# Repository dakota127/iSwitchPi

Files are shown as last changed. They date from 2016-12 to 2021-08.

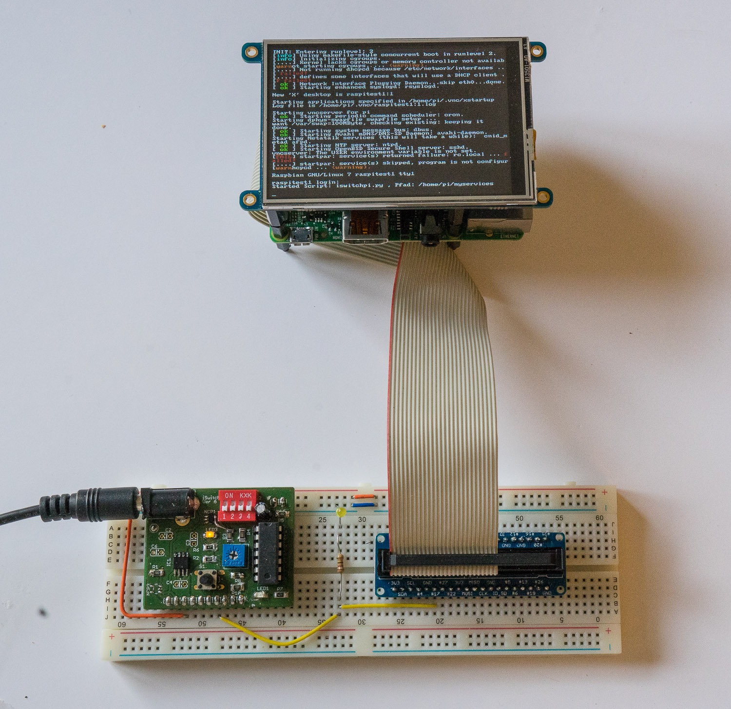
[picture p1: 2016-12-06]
Docu/supporting docu/iswitchpi_testwithpi.jpg

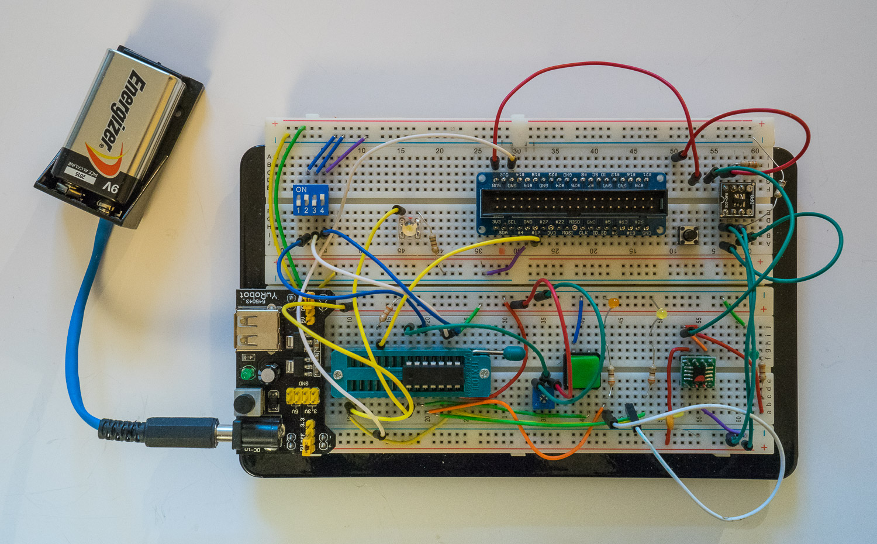
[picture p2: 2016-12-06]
Docu/supporting docu/iswitchpi_testsetup.jpg

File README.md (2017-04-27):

# iSwitchPi
Intelligent Power Switch for Raspberry Pi 

Native Raspberry Pi does not have an On/Off switch and there is no easy way
to shutdown the Pi while keeping the filesystem intact.
This Intelligent Power Switch allows just that: 
Power-On the Pi by pressing a pushbutton and also properly Power-Off
the Pi with another press on the same button.
The intelligence is provided by a program running in an AVR MCU ATtiny44.
This C-program implements a Finite State Machine in the MCU.
A small Python script is running in the Pi itself. 
Just one GPIO-Pin is used for two-way communication.
In addition, a variable frequency square wave is available for externally interrupting the Pi.

Formfactor: Raspi hat with 2x20 Pins for other hats on top of iSwitchPi.

Full Documentation, Code and EagleCAD files on GitHub. 
Documentation is in English and German.
Quick Start guide explains installation.  
See state diagram to understand operation of iSwitchPi

Also check out my project webpage at 
http://projects.descan.com/projekt5.html

Update April 2017:
In April of 2017 an update was made to the firmware in the ATtiny44. 
A user requested an auto-power-on functionality: the Pi should restart 
unattended (meaning without the need to press the ON-pushbutton) when 5 Volt comes back after a power failure. 
State 0 was added to the state diagram  and position 4 of dip-switch 3 is used to select/deselect this feature.

Free to use, modify, and distribute with proper attribution.
Frei für jedermann, vollständige Quellangabe vorausgesetzt.

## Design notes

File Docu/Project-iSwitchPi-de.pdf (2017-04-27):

# Projektbeschreibung iSwitchPi

# Intelligenter Power Switch für Raspberry Pi

Beschreibung eines intelligenten Ein/Aus-Schalters für den Raspberry Pi

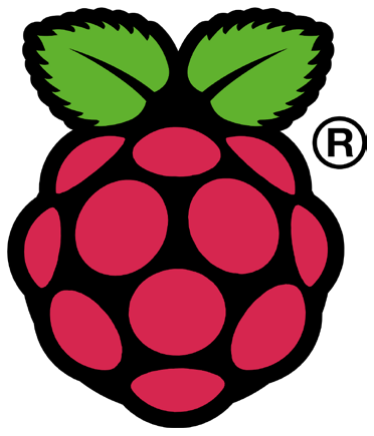
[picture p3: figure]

### Intelligent Power Switch Seite 3

Inhaltsverzeichnis

## 1. Was ist ein Raspberry Pi

Der Raspberry Pi (genannt Pi) ist ein kreditkarten-kleiner und preisgünstiger (45 CHF) Linux Computer der sich seit seiner Einführung vor bald 4 Jahren grosser Beliebtheit erfreut und der bereits mehrere Millionen Mal verkauft wurde. Im Internet finden sich unzählige Projektbeschreibungen; alles Mögliche und Unmögliche wird mit diesem Micro-Computer gebaut. Der Initiant Eben Upton ist Engländer und in folgendem Video auf YouTube erklärt die Geschichte des Pi.
Eben Upton on YouTube (https://www.youtube.com/watch?v=6xFzVuxldqs)
Der Pi hat 4 USB-Anschlüsse, einen Lan-Anschluss, ein HDMI-Anschluss für Monitor und einen Audio-Video-Ausgang. Ebenfalls auf dem Board ist ein Anschluss für die Pi-Camera - eine HD-fähige Kleinst-Camera für Fotos und Video. Was den Pi auszeichnet, ist die 40-polige Steckerleiste. Viele dieser Anschlüsse sind General Purpose Input/Output Pins, welche in Progammen angesteuert/gelesen werden können. Es gibt in der Zwischenzeit vielfältige Expansion Boards von unzähligen Anbietern. Der Pi konsumiert bloss 1 Watt Leistung: 5V und 100mA Strom.
Dieses Maschinchen hat mich von Anfang an fasziniert, ich hatte mir in 2012 eines angeschafft. Nach einigem Probieren legte ich es auf die Seite - fand einfach kein wirkliches Projekt. Dies hat sich im Frühjahr 2014 geändert und es kam die Idee auf für ein erstes Pi-Projekt: Lampensteuerung bei Ferienabwesenheit. In der Zwischenzeit (Stand Anfangs 2016) sind bereits drei weitere Raspi-Projekte dazugekommen: Light-Painting Pixeslstab mit 144 Led und ein, wie ich es nenne, Christmax TV. Raspi und Volumio als Musikplayer in einer weihnachtlichen Box. Details zu diesen Projekten findet man auf der Projekt-Website. (http://projects.descan.com)

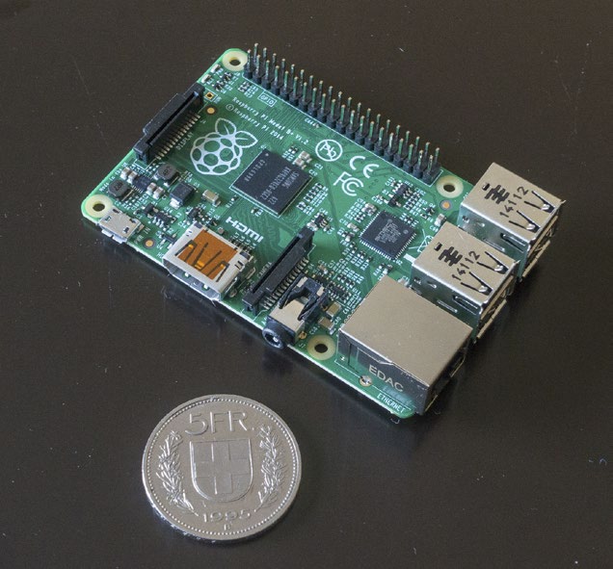
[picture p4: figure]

Der Raspberry PI Model B+

## 2. Abstract

A Raspberry Pi does not have an On/Off switch and there is no easy way to shutdown the Pi while keeping the filesystem intact.
This Intelligent Power Switch brings a clever solution to this problem: Power-On the Pi by pressing a pushbutton and also properly Power-Off the Pi with another press on the same button.
The intelligence is provided by a program running in an AVR MCU ATtiny44. This C-program implements a Finite State Machine in the MCU.
A small Python script is running in the Pi itself.
Just one GPIO-Pin is used for two-way communication between the Pi and the iSwitchPi board.
The iSwitchPi board additionally provides a square wave output with variable frequeny that can be used to trigger interrupts on the Pi.

## 3. Anforderungen

Während der Entwicklung verschiedener Gadgets mit dem Raspberry Pi tauchten immer wieder verschiedene Themen und Problemstellungen auf, für die ich gerne eine elegante Lösung gehabt hätte. So entstand der Plan, ein Add-on zu entwickeln. Folgende Anforderungen wurden definiert:
- Eine elegante Lösung für das Ein- und Ausschalten des Pi‘s zu haben.
- Das Bauteil soll in der Form eines Pi-Hats erstellt werden.
- Es soll bloss ein einziger GPIO-Pin des Pi für die Kommunikation verwendet werden.
- Das Bauteil soll wahrnehmen können, wenn der Pi nicht mehr läuft. Es soll in diesem Fall die Power -Down Sequenz gestartet werden.
- Das Bauteil soll überdies ein Rechteck-Signal von 0.5 Hz bis ca. 100 Hz erzeugen - viele Pi-Anwendungen benötigen eine externe Rechteck-Quelle, mit welcher Timer-Interrupts realisiert werden können. Ein Mikrocontroller erledigt diese Aufgabe ohne viel Programmier-Aufwand.

Wichtigste Anforderung: Bekanntermassen ist das Ausschalten eines Raspberry Pi (Power Off) - genauso wie das Ausschalten jedes anderen Computers - in zwei Schritten zu bewerkstelligen:
- a: der Pi muss ordentlich mit einem Shutdown oder halt Command heruntergefahren werden - dies kann nur in einem Stück Software auf dem Pi erledigt werden.
- b: erst danach kann extern die Stromzufuhr gekappt werden.

Das Einschalten ist dagegen simpel: Stromzufuhr einschalten und der Pi bootet und beginnt mit der vorgesehenen Arbeit.
Es gibt auf dem Markt verschiedene Add-ons zu kaufen, welches das Ein-Ausschalt-Problem lösen. Sie bestehen meist aus einer kleinen gedruckten Schaltung mit Anschlüssen für Drucktasten, 5 V und anderen nötigen Verbindungen. Diese kleinen Bauteile funktionieren gut, und es ist nicht nötig, die genaue interne Funktionsweise zu verstehen.
Dieses Projekt soll die genannten Anforderungen in Hardware und Software realisieren.

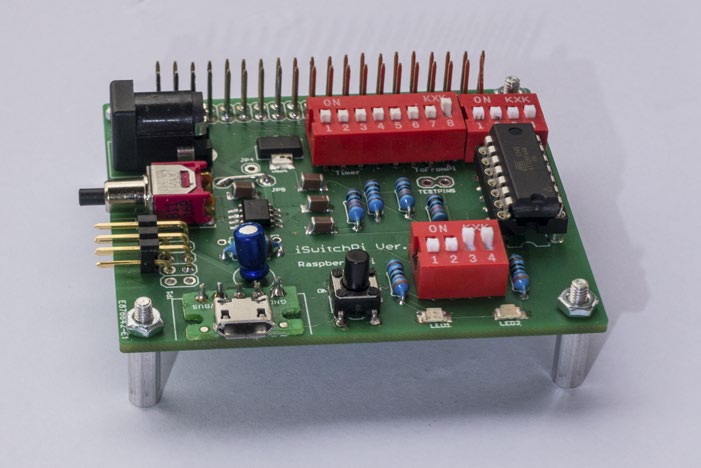
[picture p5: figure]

Die fertige iSwitchPi Platine

## 4. Vorgehen

## 4.1 Umschau auf dem Markt

Zuerst wurden einige auf dem Markt angebotenen Add-ons genauer studiert. Folgende Produkte und/oder Anleitungen wurden unter die Lupe genommen:
- Pi-Supply der Englischen Firma Pi-Supply. (https://www.pi-supply.com/) Dieses Add-on war schon bei mir im Einsatz, es funktioniert sehr gut, ungünstig ist jedoch, dass für Einschalten und Ausschalten zwei verschiedene Drucktasten verwendet werden. Die eingesetzte elektronische Schaltung ist an anderer Stelle im Internet zu finden. Kommt wegen der Lösung mit zwei Tasten nicht in Frage. Benötigt 2 GPIO Pins beim Pi.
- Pi-Shutdown Button bei Instructables: (http://www.instructables.com/id/Raspberry-Pi-Shutdown-Button/) Lösung mit embedded Controller ATtiny13/85. Dies kommt der Vorstellung schon sehr nahe.
- ATX-Raspi von LowPowerLab. (https://lowpowerlab.com/shop/ATXRaspi-R2) Dieses Produkt kommt den Anforderungen schon weit entgegen, die kleine Platine könnte als Tochterplatine eingesetzt werden. Intelligenz wird durch einen embedded Controller geleistet.
- ykrud von Yepkit. (https://www.yepkit.com/products/ykrud) Auch dieses Produkt scheint durchdacht - und dient als Anstoss, eine eigene Lösung zu entwickeln. Yepkit braucht aber 2 GPIO Pins des Pi.

Da bereits einige Kenntnisse in der Programmierung vom Atmel Mikrocontrollern vorhanden war, entschied ich mich, eine der obigen Lösungen etwas abgewandelt selbst zu entwickeln. Es soll ein ATtiny44 Mikrocontroller verwendet werden. Details dazu siehe Datenblatt. (http://www.atmel.com/images/doc8006.pdf)

## 4.2 Erkenntnis

Alle oben beschriebenen Add-ons bestehen aus 2 Komponenten, welche in bestimmter Weise zusammenarbeiten:
- Komponente A: eine kleine Schaltplatine, welche Elektronik-Komponenten enthält, die das Ein-/ Ausschalten steuern. Sie ist mit dem Pi verbunden - die Stromversorgung des Pi geschieht also NICHT über den Micro-USB Anschluss. Zudem werden meist 2 GPIO-Pins des Pi für die Kommunikation belegt. Angestrebt wird jedoch die Verwendung eines einzigen GPIO Pins.
- Komponente B: ein Python Script, welches im Pi nach dem Boot gestartet wird.

Es ist klar, dass die eigene Lösung derselben Idee folgt.

Der Intelligente Power Switch wird also ebenfalls aus eine externen Elektronik-Komponente sowie einem Python Script bestehen.

## 5. Lösungsübersicht

Das hier beschriebene Add-on wird realisiert mit einer gedruckten Schaltung in der Grösse 65x56.5 mm. Herz der Schaltung ist ein Mikrocontroller ATtiny44, für den ein C-Programm entwickelt wurde, welches die gewünschten Funktionen implementiert (Firmware). Die kleine Platine kann in ein Breadboard gesteckt werden. Diese Platine wird iSwitchPi genannt.
Die Lösung stellt sich in der Übersicht so dar

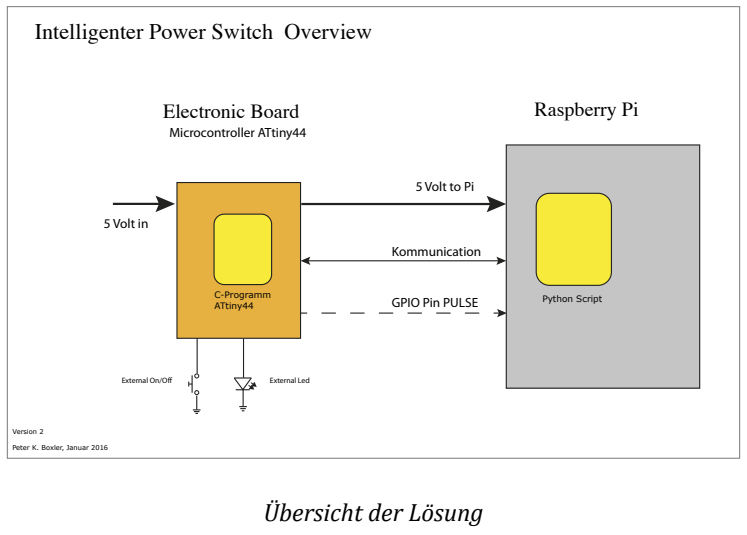
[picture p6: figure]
Version 2; Peter K. Boxler, Januar 2016; 5 Volt in; External On/Off; External Led; 5 Volt to Pi; Microcontroller ATtiny44; GPIO Pin PULSE; Kommunication; Raspberry Pi; Python Script; Electronic Board; C-Programm ATtiny44; Intelligenter Power Switch Overview; Übersicht der Lösung

Das Elektronik-Board (genannt iSwitchPi) sorgt für das Timing des Ein-Ausschalten des Pi. Im Pi läuft ein Shutdown-Script, welches via einen GPIO Pin mit dem iSwitchPi kommuniziert. Der iSwitchPi liefert zudem das Rechteck-Signal an den Pi.

## 6. Problembeschreibung, Anfoderungen

Erster Schritt jedes Elektronik- oder Software-Problems ist die genaue Analyse der Anforderungen. Neben der Ein-Ausschaltfunktion bestehen noch andere Anforderungen an das zu entwickelnde Bauteil.

Das vorliegende Problem eignet sich hervorragend zur Modellierung mittels einem Endlichen Automaten (Finite State Machine). Ein solcher Automat hat definierte Eingänge, Zustände, Übergänge zwischen Zuständen und ebenfalls definierte Ausgänge. Übergänge zwischen Zuständen werde durch Änderungen in den Inputsignalen verursacht. Dies wiederum hat Änderungen in den Output-Signalen zur Folge.

### Intelligent Power Switch Machine

Inputs | Outputs

### Clock

Problembeschreibung in Worten:
Es soll nur eine Drucktaste für Ein/Ausschalten/Reboot des Pi geben. Ist der Pi ausgeschaltet, genügt ein kurzer Druck auf die Taste, um den Pi mit Strom zu versorgen. Läuft der Pi, so kann mit einem kurzen Druck auf dieselbe Taste der Shutdown des Pi eingeleitet werden und nach einer definierten Verzögerungszeit wird auch die Stromzuführung zum Pi unterbrochen. Läuft der Pi, so kann mit einem langen Tastendruck ein Reboot des Pi ausgelöst werden - die Stromzufuhr bleibt in diesem Fall erhalten. Läuft der Pi und es wird ein Shutdown via ein Terminal Fenster ausgelöst (oder es erfolgt ein programmgesteuerter shutdown des Pi) , so soll dies die Schaltung feststellen und die Stromzufuhr nach der definierten Verzögerungszeit unterbrechen.
Die Stromversorgung des Pi soll aber auch ohne Rückmeldung des Pi aufrechterhalten werden können
- beispielsweise dann, wenn das Python Shutdown-Script noch nicht aktiviert ist oder wenn es fehlerhaft ist.

Eine solche Beschreibung in Worten ist immer etwas undeutlich, es sind meist Mehrdeutigkeiten vorhanden und die Funktion ist nicht wirklich genau beschrieben. Der vorliegende Fall wird vorzugsweise mit einem sog. ‚Endlichen Automaten‘ (Finite State Machine) modelliert.

## 6.1 Weitere Anforderungen

Das iSwitchPi Board muss auch noch folgende Anforderungen erfüllen:
- Ein-/Ausschalter oben auf dem Borad, von oben zu bedienen
- Zusätzlicher Ein-/Ausschalter seitlich, für den Fall, dass der erste Schalter wegen stacking nicht zugänglich ist
- Pin-Steckanschluss für externen Ein-/Ausschalter und externe Led für den Fall, dass der Pi in einem Gehäuse montiert ist und onboard-Schalter und Led nicht zugänglich und/oder sichtbar sind.
- 5 Volt Input via Barral Jack 5.5/2.1 mm oder via UBS-Micro Buchse aber auch via seitlichen Pin-Stecker.
- 5 Volt Zuführung zum Pi soll unterbrochen werden können (dauerhaft, durch Weglassen einer Lötbrücke), damit eventuell andere Beschaltung vorgenommen werden kann.
- Auf Ausschnitte für Kamera-Anschluss und Display-Anschluss wird verzichtet - dies wäre für einen ordentlichen Pi-Hat aber Bedingung.
- Auf Sicherung gegen Ueberspannung und verkehrte Polarität wird vorläufig verzichtet.

## 7. Komponente A: Elektronik

## 7.1 Zustands-Diagramm

Der iSwitchPi implementiert in Software und Hardware die Ein-/Ausschaltfunktion der Pi-Stromversorgung. Nach ein paar Versuchs-Skizzen wurde folgendes Zustands-Diagramm (State Diagram) für die Endliche Maschine gefunden. Das Zustanddiagramm und die Zustandtabellen definieren das zu erstellende C-Programm für den ATtiny44. Der Pi wird mittels eines Scripts (siehe weiter hinten) regelmässig Pulse senden, die signalisieren: ich bin noch am Leben, stell mir bitte den Strom nicht ab.

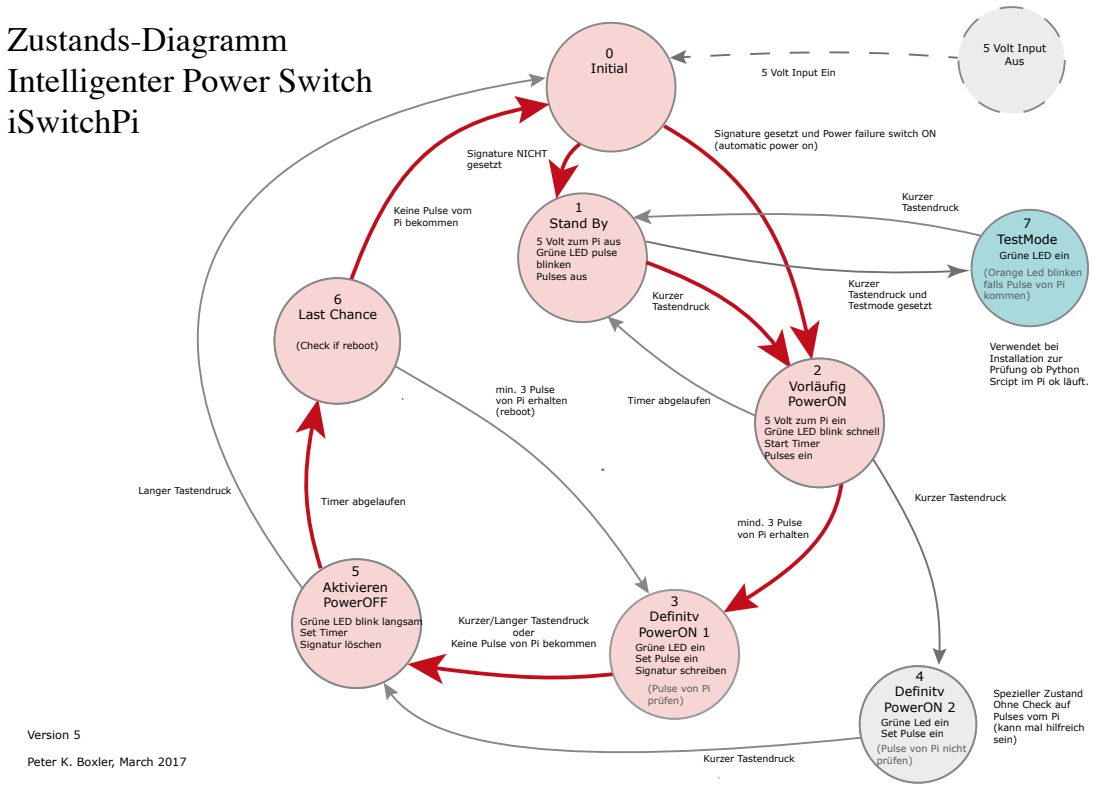
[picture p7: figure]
Version 5; Peter K. Boxler, March 2017; 1 Stand By; 0 Initial; 6 Last Chance; 3 PowerON 1; 4 PowerON 2; (do not check on Pi); Kurzer Tastendruck; Kurzer Tastendruck und Testmode gesetzt; mind. 3 Pulse von Pi erhalten; Kurzer/Langer Tastendruck oder Keine Pulse von Pi bekommen; Timer abgelaufen; min. 3 Pulse von Pi erhalten (reboot); Keine Pulse vom Pi bekommen; 5 Volt Input Ein; 5 Aktivieren PowerOFF; Grüne LED blink langsam Set Timer Signatur löschen; 5 Volt zum Pi aus Grüne LED pulse blinken Pulses aus; Langer Tastendruck; 2 Vorläufig PowerON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

Signature gesetzt und Power failure switch ON

Zustandsdiagramm 1

## 7.2 Input und Output

Dies sind alle Eingangssignale des Automaten
(Each Input can be one or zero)
Eingang | Abkürzung | Quelle
Kurzer Tastendruck | KT | Drucktaste
Langer Tastendruck | LT | Drucktaste (>1.5 sec)
TimerSignal | TS | Timer erreicht definierte Zeit
SignalFromPi | SPi | Es kommen Pulse vom Pi
Test Modus eingestellt | TM | Dip-Switch

Ausgänge des Automaten

Ausgang | Abkürzung | Was ist das
5 Volt für Pi | 5V | 5 Volt zum Pi ein oder aus

Led an | Ledon/Ledoff | Grüne Led ist dauerhaft ein oder aus
Led blink slow | Ledsl | Grüne Led blinkt langsam
Led blink fast | Ledfst | Grüne Led blinkt schnell
Signal zum Pi für Reboot | StPireb | Sende einen Pulse zum Pi
Signal zum Pi für Shutdown | StPishut | Sende 2 Pulse zum Pi
Start Timer | STo oder STf | On /Off (meint start/stop Timer)
Pulsgenerator | ON/OFF | Pulsgenerierung ON/OFF

## 7.3 Zustands Tabelle

Die Zustandstabelle beschreibt die Funktion des endlichen Automaten komplett. Diese Funktion wird durch das C-Programm implementiert. Ein bestimmter Zustand plus Kombination von Eingangssignalen führt zu einem neuen Zustand. Implizit: ohne Änderung der Eingangssignale verbleibt der Automat im aktuellen Zustand (x heisst: irrelevant).

Zustand | Eingänge | Nächster Zustand
| SK | LK | TS | SPi | TM
1 Stand by | 1 | x | x | x | | 2 Vorläufiges Einschalten
1 Stand by | 1 | x | x | x | 1 | 7 Test Modus
2 Vorläufiges Einschalten | x | x | 0 | 1 | | 3 Power On-1
2 Vorläufiges Einschalten | x | x | 1 | 0 | | 1 Stand by
2 Vorläufiges Einschalten | 1 | x | x | x | | 4 Power On-2
3 Power On-1 | 0 | 0 | x | 0 | | 5 Ausschalten aktivieren
3 Power On-1 | 1 | 0 | x | 0 | | 5 Ausschalten aktivieren
3 Power On-1 | 0 | 1 | x | 0 | | 5 Ausschalten aktivieren
4 Power On-2 | 1 | x | x | x | | 5 Ausschalten aktivieren
5 Ausschalten aktivieren | x | x | 1 | 0 | | 1 Stand by
5 Ausschalten aktivieren | x | 1 | x | x | | 1 Stand by
6 Last Chance | x | x | x | 0 | | 1 Stand by
6 Last Chance | x | x | x | 1 | | 3 Power On
7 Test Modus | X | | | | | 1 Stand By

## 7.4 Eingangs-Aktivitäten der Zustände

Jeder Zustand des Automaten hat im allg. sog. entry-actions, also Aktivitäten, die beim Eintritt in den Zustand genau einmal ausgeführt werden. Dies sind meist Änderungen in den Output-Signalen.

Zustand | Eingangs-Aktivität
1 Stand by | Stromzufuhr unterbrechen Grüne Led Pulse blink Timer stoppen Pulsgenerator stoppen
2 Vorläufiges Einschalten | Stromzufuhr einschalten Grüne Led schnell blinken lassen Timer starten Pulsgenerator starten
3 Power on-1 (Normalbetrieb) | Grüne Led voll einschalten Timer stoppen
4 Power on-2 (spezieller Betrieb) | Grüne Led voll einschalten Timer stoppen
5 Auschalten aktivieren | Grüne Led langsam blinken lassen Timer starten
6 Last Chance | nichts

7 Test Modus | Stromzufuhr einschalten Grüne Led voll einschalten

## 7.5 Elektrisches Schema

Die Hardware-Komponente des iSwitchPi soll in Form eines Raspberry Hats aufgebaut sein. Anwendung ist einfach: Aufstecken auf den Pi, 5 Volt Spannungsversorgung anschliessen und fertig. Es können weitere Hats auf den iSwitchPI gesteckt werden (stacking).
Das elektrische Schema besteht aus diesen Komponenten:
Die 5 Volt Spannungsversorgung des Pi wird durch einen High-Side Switch MCP2505 ein-/ausgeschaltet. Dieses Bauteil hat im Ein-Zustand einen Spannungsabfall von nur 15 mV und kann etwas mehr als 2 Ampère schalten.
Die Eingangsspannung von 5 Volt wird für den Mikrocontroller im Baustein LM1171MP-3.3 auf 3.3 Volt reduziert. Damit ist auch die Kommunikationsleitung für den Pi mit diesem Pegel angesprochen (GPIO Pins für den Pi dürfen max. diese Spannung haben).
Im Pi läuft ein Python Script (iswitchpi.py), welches am gewählten GPIO Pin durch regelmässige Pulse meldet ‚ok ich laufe‘. Das Script kann jedoch auch Pulse vom iSwitchPi empfangen (via Interrupt-Handler) und die Anzahl der eintreffenden Pulse bestimmen die Art des Commands, der ans OS abgesetzt wird: shutdown halt oder reboot.
Das Herz des iSwitchPi ist ein ATtiny44 Mikrocontroller. Allein für die Steuerung des Pulsgenerators und dessen Output werden 5 Pins benötigt - deshalb genügt ein ATtiny85 mit seinen total 5 Pins nicht. C-Programm (Firmware) für den Mikrocontroller siehe weiter hinten.
Die Schaltung wurde im Programm Eagle PCB gezeichnet - das Programm erstellt ebenfalls das Layout der gedruckten Schaltung (mit einiger Handarbeit). Es ergab sich eine Platine in der Grösse eines Pi Hats.

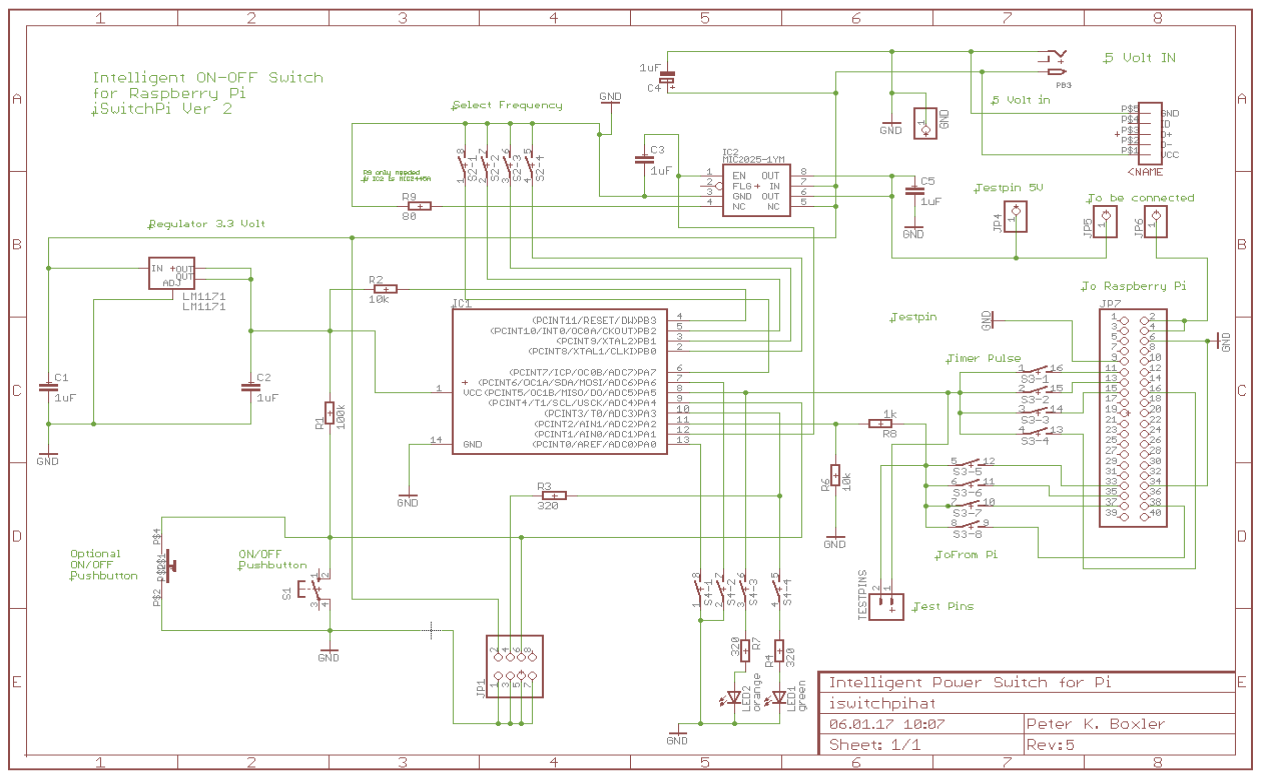
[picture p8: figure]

Schema iSwitchPi

Note:
Zukünftige Versionen des iSwitchPi werden einen Schutz gegen falsche Polarität brauchen. Dies wird dieselbe Schaltung sein, wie sie auch auf dem Raspberry selbst vorhanden ist. Siehe diesen Text für Details:

Raspberry voltage protection.

## 7.6 Gedruckte Schaltung

Nachdem das Board mittels des Programms Eagle PCB designed wurde (auf dem Mac) entstand eine Output-Datei iswitchpihat.brd. Mit dieser Datei kann eine geeignete Firma eine gedruckte Schaltungsplatine herstellen. Für iSwitchPi wurd die Firma Eurocircuits (http://www.eurocircuits.de) gewählt. 10 Platinen kosten rund 90 Euro. Besonderheiten des Boards: Für den Mikrocontroller ATtiny44 ist ein 14-Pol IC-Sockel vorgesehen. Für dessen Neuprogrammierung ist deshalb auf dem Board keine ICSP-Schnittstelle vorhanden: Der Chip wird abgezogen und in den Zero-Force-Sockel eines Programmers gesteckt.
Die Platine wird teilweise mit SMD-Komponenten der Grösse 1206 bestückt - das erfordert einige Erfahrung für das Löten.
Die ersten 10 Prototyp-Platinen waren fehlerfrei und bislang wurden 4 Stück davon bestückt und gelötet (Stand Dezember 2016). Erste Tests sind erfolgreich.
Einige Löcher waren mit zu geringem Durchmesser und es wird eine neue Version der Platine erstellt werden - mit zusätzlichen Komponenten für den Polaritäts-Schutz - siehe weiter oben.

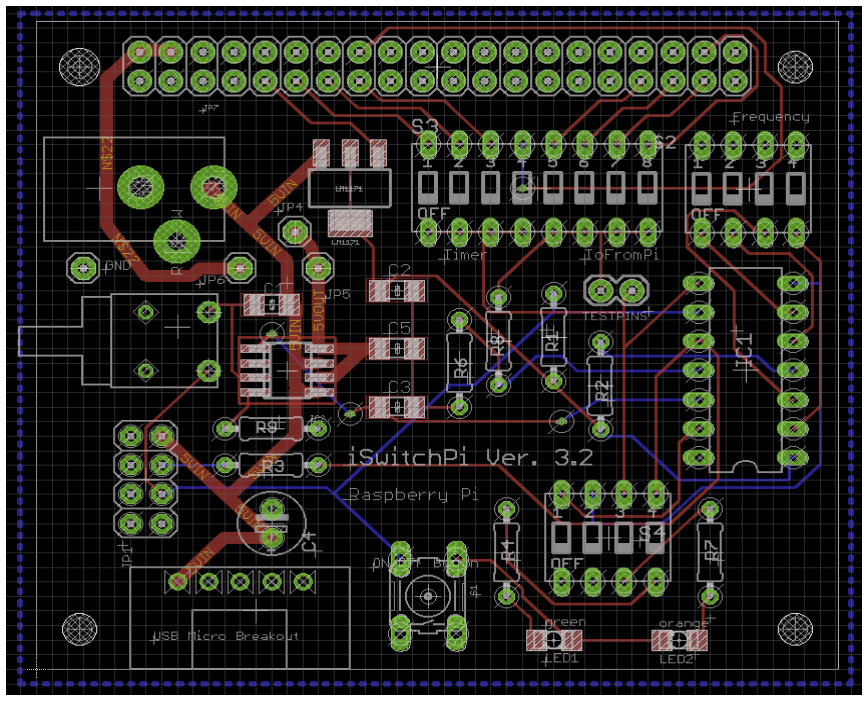
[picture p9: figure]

Gedruckte Schaltung iSwitchPi (Version 2)

## 7.7 Pulsgenerator

Der Pulsgenerator erzeugt kurze Rechteckpulse (Duty Cycle ca. 10%) mit verschiedenen Frequenzen. Durch einen DIP-Schalter kann die produzierte Frequenz eingestellt werden:

- fixe Frequenz wählbar 0.5/1/5/10/50/100/500 Hz

Die Frequenz kann mit den drei rechten Schaltern des DIP-Schalters gewählt werden. Mit 3 Schaltern sind 8 Frequenzen wählbar.

## 7.8 Kommunikation zwischen Pi und iSwitchPi

Das im folgenden beschriebene Python Script im Pi sendet prinzipiell jede Sekunde einen Puls auf der Kommunikations-Leitung auf dem definierten GPIO Pin. Diese Pulse signalisieren: ich lebe noch.
Das Programm im ATtiny44 ist prinzipiell immer auf Empfang, um diese Pulse zu bekommen. Kommen keine Pulse mehr, so wird angenommen, dass der Pi nicht mehr läuft oder sich in einem reboot-Prozess befindet. Die Power-Off Sequenz wird dann eingeleitet.
Wird die Drucktaste kurz oder lang gedrückt (shutdown oder reboot), so wird dies dem Script im Pi mitgeteilt durch Senden von Pulsen: ein Puls bedeutet shutdown, zwei Pulse bedeuten reboot.
Diese Pulse werden jedoch erst gesendet, nachdem ein Pulse vom Pi eingetroffen ist - nur dann ist sicher, dass der Pi wieder auf Empfang ist.
Folgendes Schema soll dies verdeutlichen.

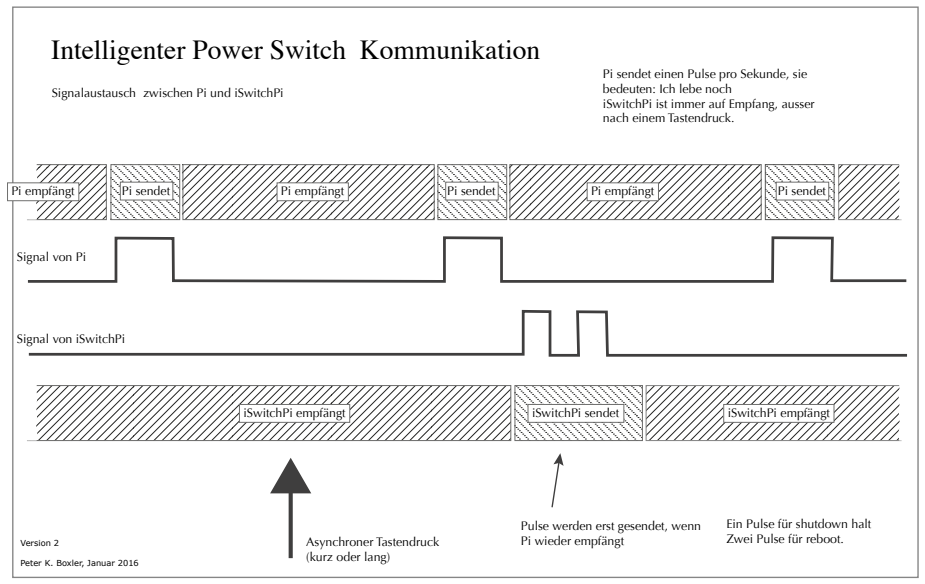
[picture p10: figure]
Version 2; Peter K. Boxler, Januar 2016; iSwitchPi empfängt; iSwitchPi sendet; Pi empfängt; Pi sendet; Signal von Pi; Signal von iSwitchPi; Signalaustausch zwischen Pi und iSwitchPi; Asynchroner Tastendruck (kurz oder lang); Pulse werden erst gesendet, wenn Pi wieder empfängt; Ein Pulse für shutdown halt Zwei Pulse für reboot.; Pi sendet einen Pulse pro Sekunde, sie bedeuten: Ich lebe noch iSwitchPi ist immer auf Empfang, ausser nach einem Tastendruck.

## Intelligenter Power Switch Kommunikation

Schema der Kommunikation

## 7.9 Programm im ATtiny44

Das Programm für den Mikrocontroller wird aus 2 C-Programmen kompiliert:
- Implementierung der Endlichen Maschine mit 7 Zuständen (iswitchpi.c)
- Implementierung des Pulsgenerators mit Hilfe von Timer 1 (square.c)

Die Verwendung der I/O-Pins des ATtiny ist im Sourcecode dokumentiert. Das C-Programm implementiert die Endliche Maschine mit 7 Zuständen gemäss der Zustandstabelle. Die Drucktaste für die Auslösung der verschiedenen Funktionen ist entprellt (debounce) mit C-Code von Peter Dannegger. Der Code ist auf Mikrocontroller.net (http://www.mikrocontroller.net/topic/48465) publiziert und diskutiert. Er funktioniert prima, ist aber nicht ganz einfach zu durchschauen. Ich habe zusätzlich eine Funktion key_clear() eingefügt. Damit können die Tastendrücke besser mit den Zuständen synchronisiert werden.

Der ATtiny44 muss mit 1 Mhz laufen, dies ist im Makefile spezifiziert. Die Fuses müssen also auf den Defaultwert gesetzt sein: 62 DF FF.

Zur Programmierung von AVR Mikrocontrollern gibt es ebenfalls in Mikrocontroller.net (http://www.mikrocontroller.net/articles/AVR-Tutorial) gute Tutorials.

Der Code des C-Programms ist auf der Projektwebsite verfügbar (siehe Kapitel Links).

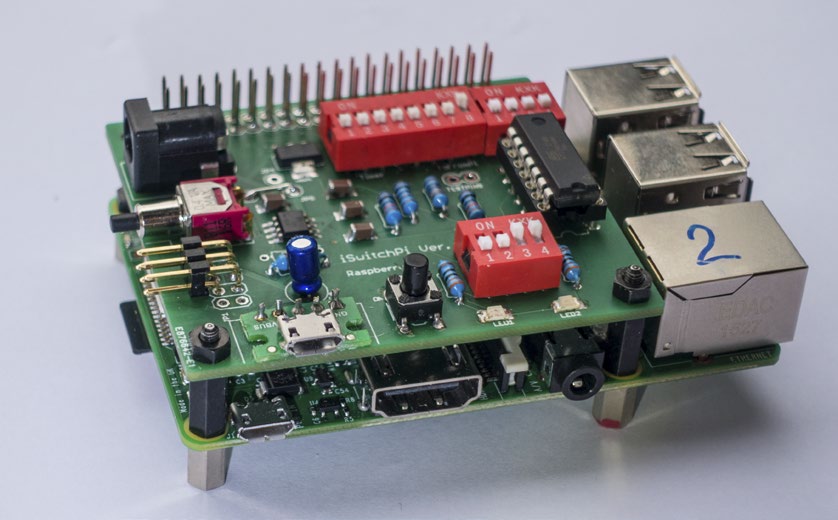
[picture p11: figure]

iSwitchPi aufgesteckt auf Pi 2 Modell B

## 8. Komponente B: Python Shutdown Script

Wie bereits in der Problembeschreibung dargelegt, arbeitet die Elektronik-Komponente mit einem Python Script iswitchpi.py zusammen, welches nach dem Boot im Pi gestartet wird (Eintrag in /etc/rc.local). Die Externe Komponente und das Script kommunizieren mittels Signalen auf einem einzigen GPIO Pin -siehe oben.
Das Script besteht im wesentlichen aus einen einfachen Loop, in welchem jede Sekunde ein 50 ms Puls am definierten GPIO Pin ausgegeben wird.
Nach dem Start wird dieser Pin jedoch auf Input gesetzt und es wird ein Interrupt-Handler auf rising abgesetzt. Vor dem Senden des Pulses wird dieser Interrupt-Handler entfernt und der Pin auf Output gesetzt. Nach dem Senden des Pulses wird der Pin wieder auf Input gesetzt und der Interrupt-Handler erneut aufgesetzt.
Der Interrupt-Handler zählt die Anzahl der Interrupts (Pulse), die seit dem letzten Senden eingetroffen sind.
Ein einzelner Interrupt führt zu Shutdown Halt und zwei Interrupts führen zu Reboot des Pi.
Siehe das Kommunikations-Diagramm weiter oben.
Das Script wird durch folgenden Eintrag in der Datei /etc/rc.local gestartet (ersetzen des Directories myservices durch eigenes Directory):

python /home/pi/myservices/iswitchpi.py [-d N] [-p nn] &

Der Commandline Parameter -d spezifiziert Debug Output (defaultwert ohne Angabe ist 1):
- 0: Kein Output (quiet)

- 1: Output bei Start und Empfangen eines Shutdown Commands (HALT oder REBOOT)
- 2: Full Debug Output for Testing.

Der Commandline Parameter -p spezifiziert den vom Script verwendeten GPIO-Pin:
- Parameter -p fehlt: es wird defaultmässig GPIO-Pin 20 verwendet (Pin38 physikalisch).
- Möglich ist - p 13 oder - p 19 oder -p 26 oder - p 20

## 9. Verwendete GPIO Pins

Für die Grundfunktion des iSwitchPi (Power On/Off) wird nur ein GPIO-Pin benötigt. Möchte man die Pulse-Funktion nutzen, ist ein zweiter GPIO-Pin notwendig.
- Kommunikation: zwischen dem iSwitchPi-Board und dem Pythonscript iswitchpy.py im Pi. Die gewünschte Pin-Nummer wird auf dem Board mittels des 4-Pol. Dip-Switches gewählt, zur Verfügung stehen die GPIO-Pins 13, 19, 20 und 26. Passend dazu muss der Pin ebenfalls im Pythonscript definiert werden. Defaultmässig verwendet das Script den Pin GPIO 20 (physikalische Pinnummer 38). Mittels Commandline-Parameter -p kann ein anderer (oben genannter Pin) definiert werden. Siehe oben.
- Korrektes Funktionieren des iSwitchPi-Boards ist nur bei Uebereinstimmung gegeben.
- Falls die Pulse-Funktion des iSwitchPi-Boards genutzt wird, ist ein weiterer GPIO-Pin notwendig. Die gewünschte Pin-Nummer wird auf dem Board mittels des 4-Pol. Dip-Switches gewählt, zur Verfügung stehen die GPIO-Pins 17, 22, 23 und 27. Passend dazu muss derselbe Pin ebenfalls in einem selbst zu erstellenden Pythonscript definiert werden. Es kann dazu der Pin-Change Interrrupt verwendet werden.

## 10. Installation von iSwitchPi

Der Quick Start Guide to iSwitchPi (English und Deutsch) beschreibt die Installation im Detail. Bemerkung
Bei der Installation ist zuerst das Python Script iswitchpi.py im Raspberry Pi zu installieren - erst nachdem das Script ordnungsgemäss läuft, kann das Board aufgesetzt werden. Ohne Oszilloskop ist es jedoch schwierig zu erkennen, ob die Pulse, die vom Script abgesetzt werden, wirklich auf dem richtigen GPIO-Pin auf dem Board ankommen. Aus diesem Grund kann das Board in den Testmodus gesetzt werden (Dip-Switch 4 Schalter 1 auf ON). In diesem Modus wirkt das Board als ‚Werkzeug‘ welches anzeigt, ob die Pulse erkannt werden. Erst wenn dies ok ist, wird das Board auch ordnungsgemäss funktionieren. Details siehe Quick Start Guide.

## 11. Testaufbau

Das Bild zeigt den ursprünglichen Breadboard-Aufbau während der Entwicklung.

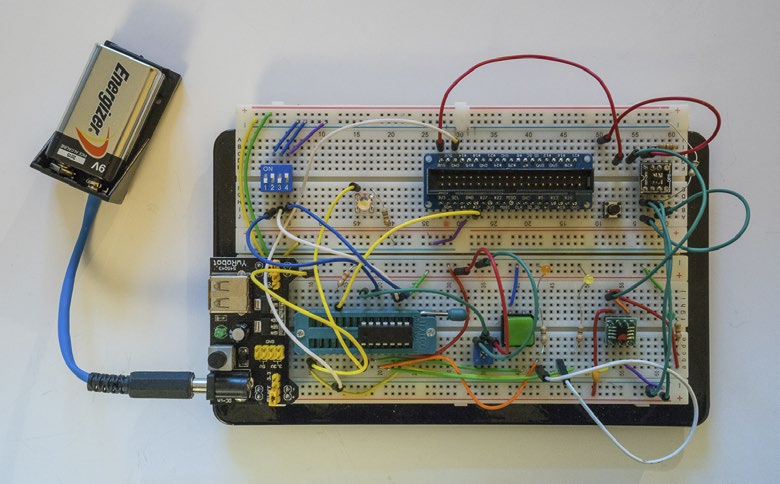
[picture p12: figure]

Testaufbau iSwitchPi auf Breadboard (ohne Pi)

## 12. Programmierung des ATtiny44

Die Entwicklung des Codes für iSwitchPi wurde auf einem Mac durchgeführt. Auf dem Mac wurde das CrossPack for AVR Development (https://www.obdev.at/index-de.html) installiert. Dieses Paket stellt folgende Komponenten zur Verfügung:
- den Compiler avr-gcc mit den notwendigen C-Libraries
- Den Commandline-Uploader AVRDUDE

Für das Schreiben des Codes in den Speicher des Mikrocontrollers (flashen oder uploaden) wurde ein einfaches Board mit einem 28-Pol Zero-Force-Sockel gebaut, siehe Bild. Dieses Board wird mittels einem 10-Pol Kabel an den Programmer Olimex AVR-ISP-MK2 angeschlossen. Dieser wiederum ist mit einem USB-Kabel mit dem Mac verbunden.
Für das Flashen wird der Uploader AVRDUDE benutzt - er wird im Makefile durch ‚make flash‘ nach der Compilation aufgerufen.

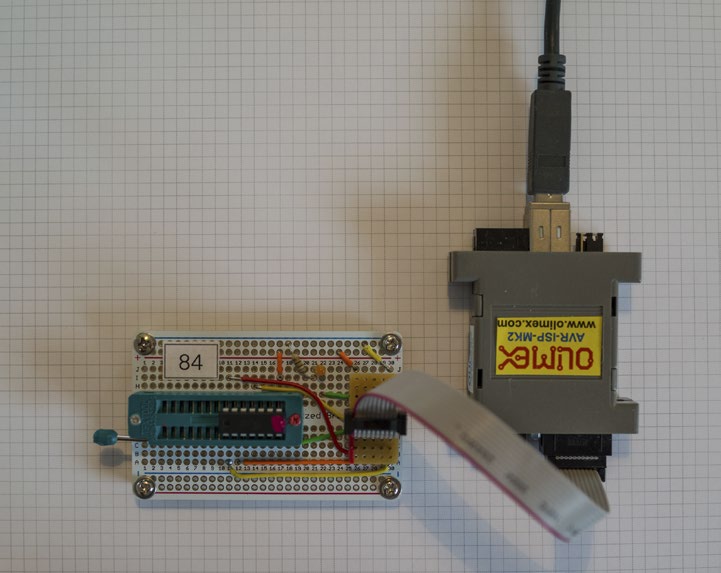
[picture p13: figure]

Programmer für ATtiny24/44/84

Bemerkung zu CrossPack Version:
Auf Mac OSX 10.9 (und höher) muss die AVRDUDE Version 5.11.1 verwendet werden, da Version 6.01 bei Verwendung eines Olimex ISPMK2 Programmers einen bug hat. Siehe hier http://www.avrfreaks.net/forum/olimex-isp-mk2-error-mac-osx-109http://www.avrfreaks.net/comment/1011406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

Ich habe deshalb CrossPack-AVR-20121203 installiert.

## 12.1 Flashing the Attiny44

Entweder mit make flash oder - falls die Datei iswitchpi.hex bereits vorhanden - ist mit Utility avrdude. Das Kommando zum Schreiben des Programms in den Mikrokontroller ist abhängig von der AVR-Werkzeugkette. In meinem Fall mit Utility avrdude und Programmiergerät avrisp2 lautet das Kommando:

avrdude -c avrisp2 -p attiny44 -P usb -U flash:w:iswitchpi.hex

## 13. Komponenten auf dem Board

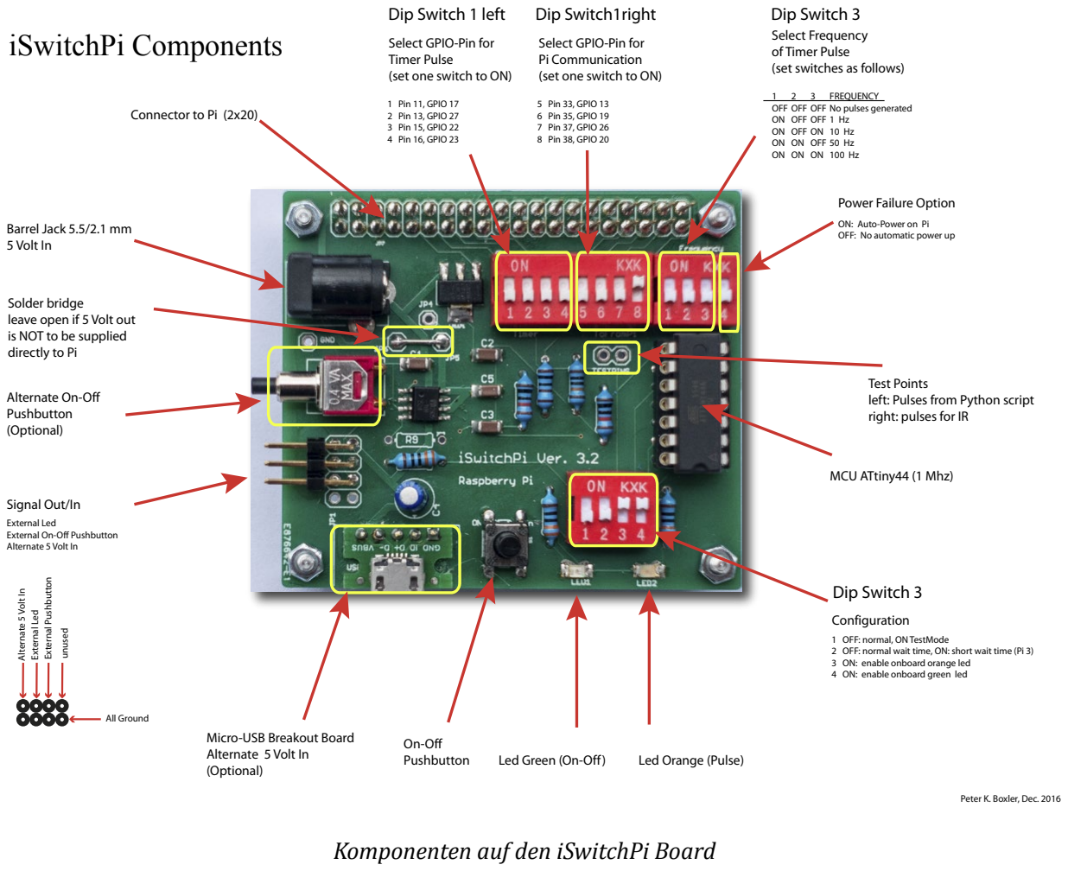
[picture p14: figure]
Led Green (On-Off); Micro-USB Breakout Board Alternate 5 Volt In (Optional); Signal Out/In; Barrel Jack 5.5/2.1 mm 5 Volt In; Solder bridge leave open if 5 Volt out is NOT to be supplied directly to Pi; Connector to Pi (2x20); Peter K. Boxler, Dec. 2016 updated March 2017; Test Points left: Pulses from Python script right: pulses for IR; Led Orange (Pulse); iSwitchPi Components; MCU ATtiny44 (1 Mhz); On-Off Pushbutton; Alternate On-Off Pushbutton (Optional); Select GPIO-Pin for Pi Communication (set one switch to ON); 5 Pin 33, GPIO 13 6 Pin 35, GPIO 19 7 Pin 37, GPIO 26 8 Pin 38, GPIO 20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

2 OFF: normal wait time, ON: short wait time (Pi 3)

## 14. Zusammenfassung

Der Versuch, die Problembeschreibung mittels endloser Automaten (Finite State Machines) zu beschreiben, hat zwar Einiges an Aufwand gekostet, hat aber die Lösungsfindung beträchtlich klarer gemacht. Das Schreiben des C-Programms für den iSwitchPi war dadurch relativ einfach; durch die Zustandsdiagramme und die Zustandstabellen war der Code klar vorgegeben. Beim Testen sind keine ernsthaften logischen Probleme des Programm-Ablaufs aufgetreten.
Was den schon immer bekannten Satz erneut bestätigt: zuerst denken, dann codieren.

## 15. Updates

Im April 2017 wurde eine Erweiterung der Firmware im ATTiny44 vorgenommen: Es wurde eine Auto-Power-On Funktion gewünscht: nach Stromausfall soll der Pi auch von selbst wieder hochfahren (also ohne Tastendruck), falls 5 Volt Stromversorgung wieder hochkommt.
Dies wurde durch einen neuen Zustand 0 einfach erreicht. Pos. 4 von Dip-Switch 2 definiert Auto-Power-on Funktionalität ON oder OFF

## 16. Links

Meine Raspberry Projekte
Projekt-Website (http://projects.descan.com)

Source Code iSwitchPi incl. Eagle Dateien GitHub (https://github.com/dakota127/iswitchpi)

Andere Links
Initial State Raspberry Pi GPIO Pins Raspberry Foundation (https://www.raspberrypi.org/documentation/configuration/pin-configuration.md)

Zum Thema Endliche Maschine http://www.mikrocontroller.net/articles/Statemachine

Tutorials zu AVR Mikrocontroller http://www.mikrocontroller.net/articles/AVR-Tutorial

Eagle PCB Design Software
http://www.cadsoft.de

Beste Firma für Ideen und Anleitungen

### https://www.adafruit.com

In der CH zu empfehlen, führt Adafruit Produkte http://www.play-zone.ch

## 17. Anhang

## 17.1 Beispiel Scripts für iSwitchPi

Im Folder sources/examples on GitHub finden sich 2 Python Scripts, welche demonstrieren, wie die Rechteck-Pulse des iSwitchPi für reglemässig sich wiederholende Aktivitäten in einem Python Script genutzt werden können.
- Script example-interrupt.py zeigt, wie durch Interrupts eine Led geblinkt werden kann. Natürlich kann man dies auch durch ein anderes Python Script erreichen - im Beispiel wird dazu eben ein Interrupt Handler eingesetzt.
- Script example-sighandler.py zeigt, wie ein Python Script gracefully (also elegant) beendet werden kann, beipielsweise wenn es mit ctrl-C abgebrochen oder wenn ein kill-Befehl abgesetzt wird. Dies ist manchmal wichtig, wenn vor dem Beenden GPIO Pins rückgesetzt werden sollen.

## 17.2 Teile Liste iSwitchPi

Part | Value | Package | Note | Supplier | PartNumber

Condensator
C1 | 1uF | SMD1206 | ceramic | Any
C2 | 1uF | SMD1206 | ceramic | Any
C3 | 1uF | SMD1206 | ceramic | Any
C4 | 1uF | E2,5-6E | | Any
C5 | 1uF | SMD1206 | ceramic | Any

IC
IC1 | MCU ATTINY44 | DIL14 | Attiny
IC2 | MIC2025-1YM | SO08 | High-Side Switch
LM117 | LM1171MP-3.3 | SOT223 | 3.3 Volt Regulator | Distrelec | 110-38-693

Led
LED1 | green | SMD 1206 | SMD 1206
LED2 | orange | SMD 1206 | SMD 1206

Resistor
R1 | 100k | 0204/7 | Any
R2 | 10k | 0204/7 | Any
R3 | 320 | 0204/7 | Any
R4 | 320 | 0204/7 | Any
R6 | 10k | 0204/7 | Any
R7 | 320 | 0204/7 | Any
R8 | 1k | 0204/7 | Any
R9 | 80 | | | Nur bei MIC2445A

DIP-Switch
S2 | DIP04S | Dip 4-Pol | Any
S3 | DIP08S | Dip 8-Pol | Any
S4 | DIP04S | Dip 4-Pol | Any

Pin Header
J1 | 1X02 | Onboard green Led On/Off
J2 | 1X02 | without Pi
JP1 | 2X04 | Input/Output

JP3 | | 1X01 | Optional 5 V IN
TestPins | | 1X02 | TestPins
JP5 | | 1X01 | 5 V to Pi, connect to JP6
JP6 | | 1X01 | 5 V to Pi, connect to JP5
JP7 | extra long pins | 2X20-BIG | GPIO Stacking Header | Adafruit | 2223

Pushbutton
S1 | 6x6 mm | B3F-10XX | Pushbutton On/Off | Adafruit | 367/1490/ P00000256 P00000681

Other
IC-Socket 14-pol | for ATtiny44 | Any

5 Volt IN
PB3 | 2.1MMJACK | Barrel Jack 5.5/2.1 mm | Adafruit | 373
PB4 | ADAUSBMICRO | USB-Micro-Brea-kout | Adafruit, Play-Zo-ne | 1833/P00001025

Only if High-Side Switch is MI-C2345A

R9 | 80 | 0204/7 | Any

Optional, second Pushbutton On/Off

PB1 | Button liegend | Pushbutton On/Off | Distrelec | 135-75-923 off-(on) 1P, 6A52-F4H9AE, Eledis

Montage
| Standoff | 4 Pieces | 11mm/2.5mm | Adafruit | 2336

## 17.3 Notizen

In der ersten Version des iSwitchPi wurde ein zusätzlicher Chip NCP702SN33 vorgesehen, der zusätlich 3.3 Volt für ein Breadbord liefern soll. Dies wurde in der Version 2 gestrichen.

Notes zu GPIO
Nicht alle GPIO Pins des Pi sind identisch. In Internet Foren findet man viele Diskussionen zur Frage des Initialzustandes (High/Low und Impedanz) der GPIO Pins nach dem Power-On des Pi. Für sehr viele (aber nicht alle) Anwendungen ist es wichtig, genau darüber Bescheid zu wissen, damit verbundene Komponenten nicht im falschen Moment schalten/aktiviert werden. Das Problem scheint aber nicht eine einfache Lösung zu haben.
Die Raspberry Foundation bietet seit 2014 eine Lösung für das Problem, siehe hier. (https://www.raspberrypi.org/documentation/configuration/pin-configuration.md)
Siehe auch diesen Blog. (http://int03.co.uk/blog/2015/01/11/raspberry-pi-gpio-states-at-boot-time/) Oder Google mit ‚raspberry gpio initial state‘.
Zusammenfassend wird gesagt, dass man für Pins, die als Input Pins verwendet werden, in jedem Fall einen Widerstand zur Strombegrenzung vorschalten sollte.

Output Pins sollten immer mittels einem 15k Widerstand nach Masse geschaltet werden, damit sie sicher Low sind, auch wenn sie Pi-intern floating sind während dem Boot.

## 17.4 Code iSwitchPi

Hier ein Ausschnit aus der C-Implementierung der Finite State Machine im Programm iswitchpi.c für den ATtiny44.

// ---- Main Loop. forever ---------------------// ---- Implements State Machine ---------------
for(;;)
{
// | _delay_ms(10); | // for testing

switch (state) {
/*------------------------------------------------------------------*/
/* | state 0 | Initial State State | */
/* | is entered upon 5 Volt Power on | */
/* | check if Pi auto power-on is selected | (dip Switch) | */
/* | if NO --> goto state 1 | */
/* | if YES --> goto state 2 | */
/*------------------------------------------------------------------*/ case state0:
if (first_time & (1<<STAT0_FIRST)) { | // first_time time throu ?
first_time =0xff; | // set first_time all other states
first_time &= ~(1<<STAT0_FIRST); | // clear first_time this state
}
tick2=0;
pastpulses=0; | // pulse counter reset (pulses from Pi)
if ( !(PINB & (1<<AUTO_POWER)) ) | // check if auto power on is required (dip switch Pos 4 ON)
state=state2; | // if YES: next state is state 2
else
state=state1; | // if NO: next state is state 1

break;

/*------------------------------------------------------------------*/
/* | state 1 | Stand-by State, all is off, waiting for short keypress | */
/* | Power to Pi ist off, led blinks short pulses | */
/* | Waiting for short keypress | */
/*------------------------------------------------------------------*/
case state1:
if (first_time & (1<<STAT1_FIRST)) { | // first_time time throu ?
PORTA &= ~( 1<<LED1 | 1<<VPOWER); | // all outputs off
key_clear( 1<<KEY0 );
blinkwhat=PULSED_Blink;
tick2=0;
blinkon=1;
pwm_stop(); | // stop pulse genaration
output on PA5
pastpulses=0; | // pulse counter reset (pulses from Pi)
first_time =0xff; | // set first_time all other states
first_time &= ~(1<<STAT1_FIRST); | // clear first_time this state
}
if (get_key_short( 1<<KEY0 )) { | // get debounced keypress
if (!(PINA & (1<<TESTPIN)) ) | // if Testpin is low: signalling TESTMODE
state=state7; | // next state is state 7
else
state=state2; | // next state is state 2
} | // leaving standby
break;

/*------------------------------------------------------------------*/
/* | state 2 | Tentative Power on, waiting for Pi to come up | */
/* | Power to Pi ist on, led is blinking fast | */
/* | Short keypress switches to state 4 | (power on without checking */
/* | whether Pi is on) | */
/*------------------------------------------------------------------*/ case state2:
if (first_time & (1<<STAT2_FIRST)) { | // first_time time throu ?
PORTA |= (1<<VPOWER); | //switch 5 volt power on
poweron_delay=POWERON_Delay_long;
if ( !(PINA & (1<<DELAYTIME)) ) {

poweron_delay=POWERON_Delay_short; | // check pin PA6 for delay times (Dip-
switch 4 Pos 2 ON)
}

blinkwhat=REGULAR_Blink;
blinkint=POWERON_Blink_int;
tick2=0; | //start timer
sekunde=0;
pwm_start(); | // start pulse generati-
on output on PA5
first_time =0xff; | // set first_time all other states
first_time &= ~( 1<<STAT2_FIRST); | // clear first_time this state
}

pwm_check();

if ((blinkwhat>0) && (sekunde > poweron_delay)) {
blinkwhat=0;
state=state1; | // Pi did not come on, so gaback to stand by
}
if (get_key_short( 1<<KEY0 )) | { | // get debounced keypress short
blinkwhat=0;
state=state4;
}
// how many pi pulses have we received ? if we have Pi is alive // so we go to state 3 (normal operation state)
if (pastpulses > 3) {state=state3;}

break;

/*------------------------------------------------------------------*/
/* | state 3 | Power ON Number 1, regular operating state | */
/* | Power to Pi ist on, led is on | */
/* | Loss of signal from Pi changes state to 5 | */
/* | Short keypress | signals Pi to shut down, changes state to 5 | */
/* | Long Keypress signals Pi to reboot, stays in state 3 | */
/*------------------------------------------------------------------*/ case state3:
if (first_time & (1<<STAT3_FIRST)) | { | // first_time time throu ?
PORTA |= (1<<LED1); | // led full on
blinkwhat=0;
key_clear( 1<<KEY0 );
first_time =0xff; | // set first_time all other states
first_time &= ~( 1<<STAT3_FIRST); | // clear first_time this state
}
pwm_check(); | // check various inputs for frequency of
pulse on PA5
if (get_key_short( 1<<KEY0 )) { | // get debounced keypress short
cli();
sendnow=1; | // set flag so IR handler can send signal
sei(); | // Interrupt enable
state=state5; | // next state 5
poweroff_delay=POWEROFF_Delay_HALT_long; | // Poweroff delay for halt
if ( !(PINA & (1<<DELAYTIME)) ) {
poweroff_delay=POWEROFF_Delay_HALT_short; | // check pin PA6 for delay times (Dip-
switch 4 Pos 2 ON)
}

}

if( get_key_long( 1<<KEY0 )) | { | // get debounced keypress long
cli();
sendnow=2; | // set flag so IR handler can send signal
sei(); | // Interrupt enable
state=state5; | // next state 5
// Pi will reboot
poweroff_delay=POWEROFF_Delay_REBOOT_long; // Poweroff delay for halt
if ( !(PINA & (1<<DELAYTIME)) ) {
poweroff_delay=POWEROFF_Delay_REBOOT_short; // check pin PA6 for delay times (Dip-switch 4 Pos 2 ON)
}

}

// check numer of pulses from Pi, zero means: Pi is not alive
if (pastpulses < 2 ) | {
state=state5; | // ok, start power off sequence
poweroff_delay=POWEROFF_Delay_HALT_long; | // Poweroff delay for halt
}
break;

/*------------------------------------------------------------------*/
/* | state 4 | Power ON Number 2, special operating state | */
/* | we do not care about pulses from Pi | */
/* | Power to Pi ist on, led is on | */
/* | Short keypress | signals Pi to shut down, changes state to 5 | */
/*------------------------------------------------------------------*/ case state4:
if (first_time & (1<<STAT4_FIRST)) { | // first_time time throu ?
PORTA |= (1<<LED1); | // led full on
blinkwhat=0;
key_clear( 1<<KEY0 ); | // ignore keypresses that might have come
| | first_time =0xff; | | // set first_time all other states
first_time &= ~( 1<<STAT4_FIRST) | ; | // clear first_time this state
}
pwm_check(); | // | Pulse generation
| | | // | Check DIP-Switch (PINB0 to PINB2)
if (get_key_short( 1<<KEY0 )) | { | // get debounced keypress short
| | cli();
sendtopi(1); | // set flag so IR handler can send signal
| | sei(); | // Interrupt enable
| | state=state5;
| | _delay_ms(10);
poweroff_delay=POWEROFF_Delay_HALT_long; | // Poweroff delay for halt

}
break;

/*------------------------------------------------------------------*/
/* | state 5 | Activate Power off, prepare to shut off | */
/* | irrelevant of signals from Pi | */
/* | Power to Pi ist still on, led is blinkng slow | */
/* | Short keypress | changes to state 4 (keep power on regardless | */
/* | of signal from Pi) | */
/* | Long keypress switches off immediately (goto state 1) | */
/* | goto stand by state if timer runs out | */
/*------------------------------------------------------------------*/ case state5:
if (first_time & (1<<STAT5_FIRST)) | { | // first_time time throu ?
blinkwhat=REGULAR_Blink; | // set led to blink
blinkint=POWEROFF_Blink_int;
key_clear( 1<<KEY0 ); | // ignore keypresses that might have come
| | pastpulses=0;
| | tick2=0; | //start timer
| | sekunde=0;
| | first_time =0xff; | | // set first_time all other states
first_time &= ~( 1<<STAT5_FIRST) | ; | // clear first_time this state
}
// | pwm_check(); | // | Pulse generation
| | | // | Check DIP-Switch (PINB0 to PINB2)
if (get_key_short( 1<<KEY0 )) { | // get debounced keypress short
| | state=state3;
}
if( get_key_long( 1<<KEY0 )) | { | // get debounced keypress long
state=state1; | // next state 5
| | | | // Pi will reboot
}

/* removed this - not in state diagram
// check Signal from Pi, how many pulses have we received
if (pastpulses > 4) | { | // Pi seems to ba alive, ok keep power on
| | state=state3;
}
*/
// wait for POWEROFF_Delay sec before switching off 5 Volt supply
if ((blinkwhat>0) && (sekunde > poweroff_delay)) | {
| | blinkwhat=0;
state=state6; | // next state is state 5
}

break;
/*------------------------------------------------------------------*/
/* | state 6 | Last Chance | (check if Pi rebooted) | */
/* | we are about to switch 5 Volt power off | */
/* | but before we do that we check the signal from Pi again : | */
/* | If further pulses came in (Pi rebooted) we keep power on | */
/* | If no more pulses came in we go to state 1 | */
/*------------------------------------------------------------------*/
case state6:
first_time =0xff; | // set first_time all other states
key_clear( 1<<KEY0 );

// check Signal from Pi
if (pastpulses > 3) {
state=state3;
}
else state=state1;

break;

/*------------------------------------------------------------------*/
/* | state 7 | TESTMODE only | */
/* | Power to Pi is switched on, green led is on | */
/* | Orange Led blinks every 3 seconds IF and only if pulses from Pi */
/* | are ok received. | */
/* | Short keypress: next state is state1 (off) | */
/*------------------------------------------------------------------*/ case state7:
if (first_time & (1<<STAT7_FIRST)) | { | // first_time time throu ?
| | PORTA |= (1<<VPOWER); | //switch 5 volt power on
PORTA |= (1<<LED1); | // led full on
| | blinkwhat=0;
| | key_clear( 1<<KEY0 );
tick2=0; | //start timer
| | sekunde=0;
| | blink_led();
| | first_time =0xff; | // set first_time all other states
first_time &= ~( 1<<STAT7_FIRST) | ; | // clear first_time this state
}
if (get_key_short( 1<<KEY0 )) { | // get debounced keypress short
| | state=state1;
}

// check Signal from Pi blink orange led when 2 pulses have been received
if (pastpulses > 2) | {
| | blink_led();
| | pastpulses=0;
| | }
| }
//---- | End of Switch Statement -----------------------------

Ende des Dokumentes.

Peter K. Boxler, Februar 2016 Updated April 2017

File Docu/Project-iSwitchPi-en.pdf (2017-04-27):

# Project iSwitchPi

# Intelligent Power Switch für Raspberry Pi

Make working with the Pi easy.

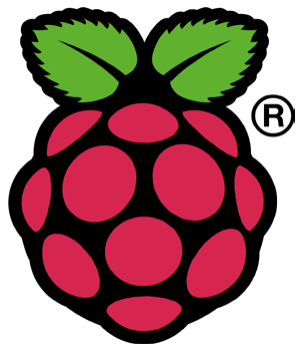
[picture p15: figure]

## Inhaltsverzeichnis

### 1. Abstract | 4 2. First Ideas | 4

2.1 Market Review | 4
2.2 Findings | 5

### 3. Overwiew | 5 4. Problem Statement | 1

4.1 Additional Requirements | 1
4.2 State-Diagram | 2
4.3 Input and Output of the machine | 2
4.4 State Diagram | 3
4.5 Activities upon entering a state | 3

### 5. Component A: Electronics | 3

5.1 Schema | 4
5.2 Printed Circuit Board | 4
5.3 Puls Generator | 5
5.4 Communication between Pi and Electronic | 5
5.5 C-Program for ATtiny44 | 6

### 6. Component B: Python Shutdown Script | 7 7. GPIO Pins used | 7 8. Install iSwitchPi | 8 9. Test Setup | 8 10. Programming the ATtiny44 | 8 11. Components on the PCB | 9 12. Conclusion | 10 13. Updates | 10 14. Links | 10 15. Attachments | 11

15.1 Example Scripts für iSwitchPi | 11
15.2 Parts List iSwitchPi | 11
15.3 Code iSwitchPi | 13

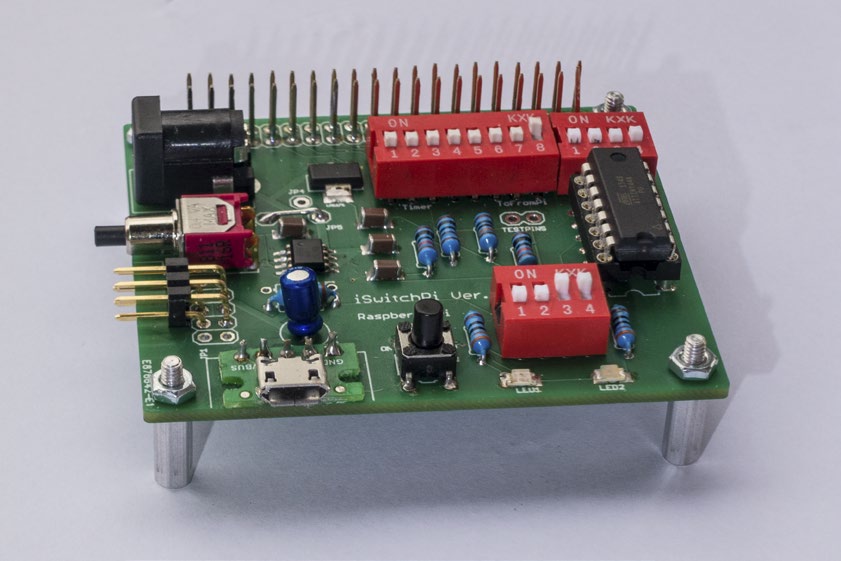
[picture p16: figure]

## Intelligent Power Switch Seite 4

# 1. Abstract

A Raspberry Pi does not have an On/Off switch and there is no easy way to shutdown the Pi while keeping the filesystem intact.
This Intelligent Power Switch brings a clever solution to this problem: Power-On the Pi by pressing a pushbutton and also properly Power-Off the Pi with another press on the same button.The intelligence is provided by a program running in an AVR MCU ATtiny44. This C-program implements a Finite State Machine in the MCU.
A small Python script is running in the Pi itself.
Just one single GPIO-Pin is used for two-way communication between the Pi and the iSwitchPi board.
The iSwitchPi board additionally provides a square wave output with variable frequeny that can be used to trigger interrupts on the Pi.
This project description presents an elegant solution for the problem of switching the Pi on and off. The goal was to have a small pc board whose functionality can be described as follows:
- one pushbutton only for power on and power off
- form factor as a Raspberry hat for eas of use
- only one communication line to the pi - in other words. only one GIPO pin used on the Pi
- awarness of the Pi‘s status (running or not running)
- only one communication line to and from the pi - in other words. only one GIPO pin used on the Pi
- square signal output capability with variable/defined frequency to be used as a timer interrupt for the Pi
- later versions usable on a breadboard.

The iSwitchPi Board

# 2. First Ideas

## 2.1 Market Review

There are a number of electronic add-ons to be found on the market - they all try (and succeed) to solve the problem of power up/down the Pi. All of them consist of two components:

- a small pcb board with connections for pushbutton, 5 Volt in, 5 Volt out, GPIO to Pi
- a small shell script or Python script running in the Pi

I found the following products and tried some of them in my own lab. None of the has an square wave generator.

- Pi-Supply from the English Company Pi-Supply. (https://www.pi-supply.com/) This add-on uses two pushbuttons for power on and power off, respectively. It uses two GPIO pins on the Pi. Works well.
- Pi-Shutdown button as decribed on Instructables. (http://www.instructables.com/id/Raspberry-Pi-Shutdown-Button/) This solution uses an embedded controller ATtiny13/85.
- ATX-Raspi from LowPowerLab. (https://lowpowerlab.com/shop/ATXRaspi-R2) This product is close to what i had in mind.
- ykrud from Yepkit. (https://www.yepkit.com/products/ykrud) This product also uses an embedded controller. Seems very ok but uses 2 GPIO pins.

## 2.2 Findings

That review showed that I needed to go back to the drawing board to start finding my own solution which is based on ideas that were used in some of the products. I decided to use an ATtiny44 microcontroller.

- There will be an electronic component (pcb board) with all the neccesary componentes and the MCU. Two different board will be made: a small board to be used on a breadboard and another (almost) hat-compliant board to be stacked on a Pi. Only ONE GPIO-Pin will be used for communication.
- There will also be a Python script that is started in the Pi at boot time.

# 3. Overwiew

The add-on will consist of pcb in the form of a Pi hat. At the heart will work a microcontroller ATtiny44 for which I developed a C program that implements the necessary logic. This is called the iSwitchPi board.
This is a overview:

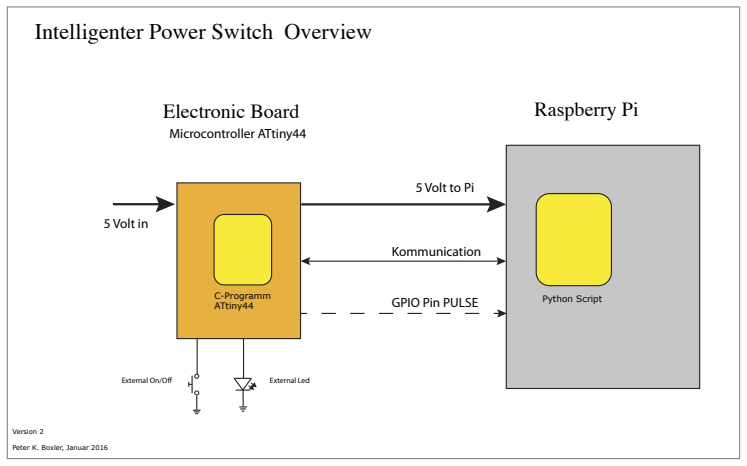
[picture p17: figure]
Version 2; Peter K. Boxler, Januar 2016; 5 Volt in; External On/Off; External Led; 5 Volt to Pi; Microcontroller ATtiny44; GPIO Pin PULSE; Kommunication; Raspberry Pi; Python Script; Electronic Board; C-Programm ATtiny44; Intelligenter Power Switch Overview

System Overview

# 4. Problem Statement

First step is always an thorough analysis of all the requirements.
I tried the following description in plain sentences:
There is a small pushbutton to switch the Pi on and off. Is the Pi switched off a short press on the pushbutton switches on the 5 Volt Power for the Pi and the led blinks fast. If the Pi does not come on (‚running‘) power is again cut after a wait time of about 30 sec.
If the Pi comes up we have normal operation, 5 volt power stays on and the led is fully on.
A short press on the pushbuttons signals to the Pi to shutdown and activates a timer. The led blinks slow. Power is cut after the timer reaches a predefined value.
A long press on the pushbutton signals the Pi to reboot - power stays on in this case.
Additionally: if the system waits for the Pi to come up a another short press on the button directs the system on keep power on without checking whether Pi is running.
If the Pi-Pin suddenly goes to low (Pi not running), the System starts the power down sequence.
That covers situations where the Pi Pi is shutdown in a terminal window.

Such a prosa description ist not very good and usually not complete. Sentences are misleading and there might be ambiguity.
That is where Finite State Machines come to the rescue. A state diagram together with a state table describes the machine completely and the transfer to C code is easy. A finite state machine has defined inputs, states, transistions and also defined outputs.

## Intelligent Power Switch Machine

Inputs | Outputs

## Clock

## 4.1 Additional Requirements

These are additional requirements for the iSwitchPi Board:

- One ON-/OFF-Switch (Pushbutton) on top of the board.
- An additional ON-/OFF-Switch (Pushbutton) sideways - in case the top switch is not reachable due to stacking.
- A pin-connector for an external ON-/OFF-Switch (Pushbutton) and external led. In case the Pi is in an enclosure.
- 5 Volt Input via Barrel Jack 5.5/2.1 mm or via UBS-Micro connector and also via the pin-connector.
- 5 Volt supply to the Pi via solder bridge. Can be taken out for other requirements (There are Pi-hats on the market that require that 5 Volt is supplied through them.
- Cutouts for camera-connector and display-connector not neded in first versions.

## 4.2 State-Diagram

# Zustands-Diagramm

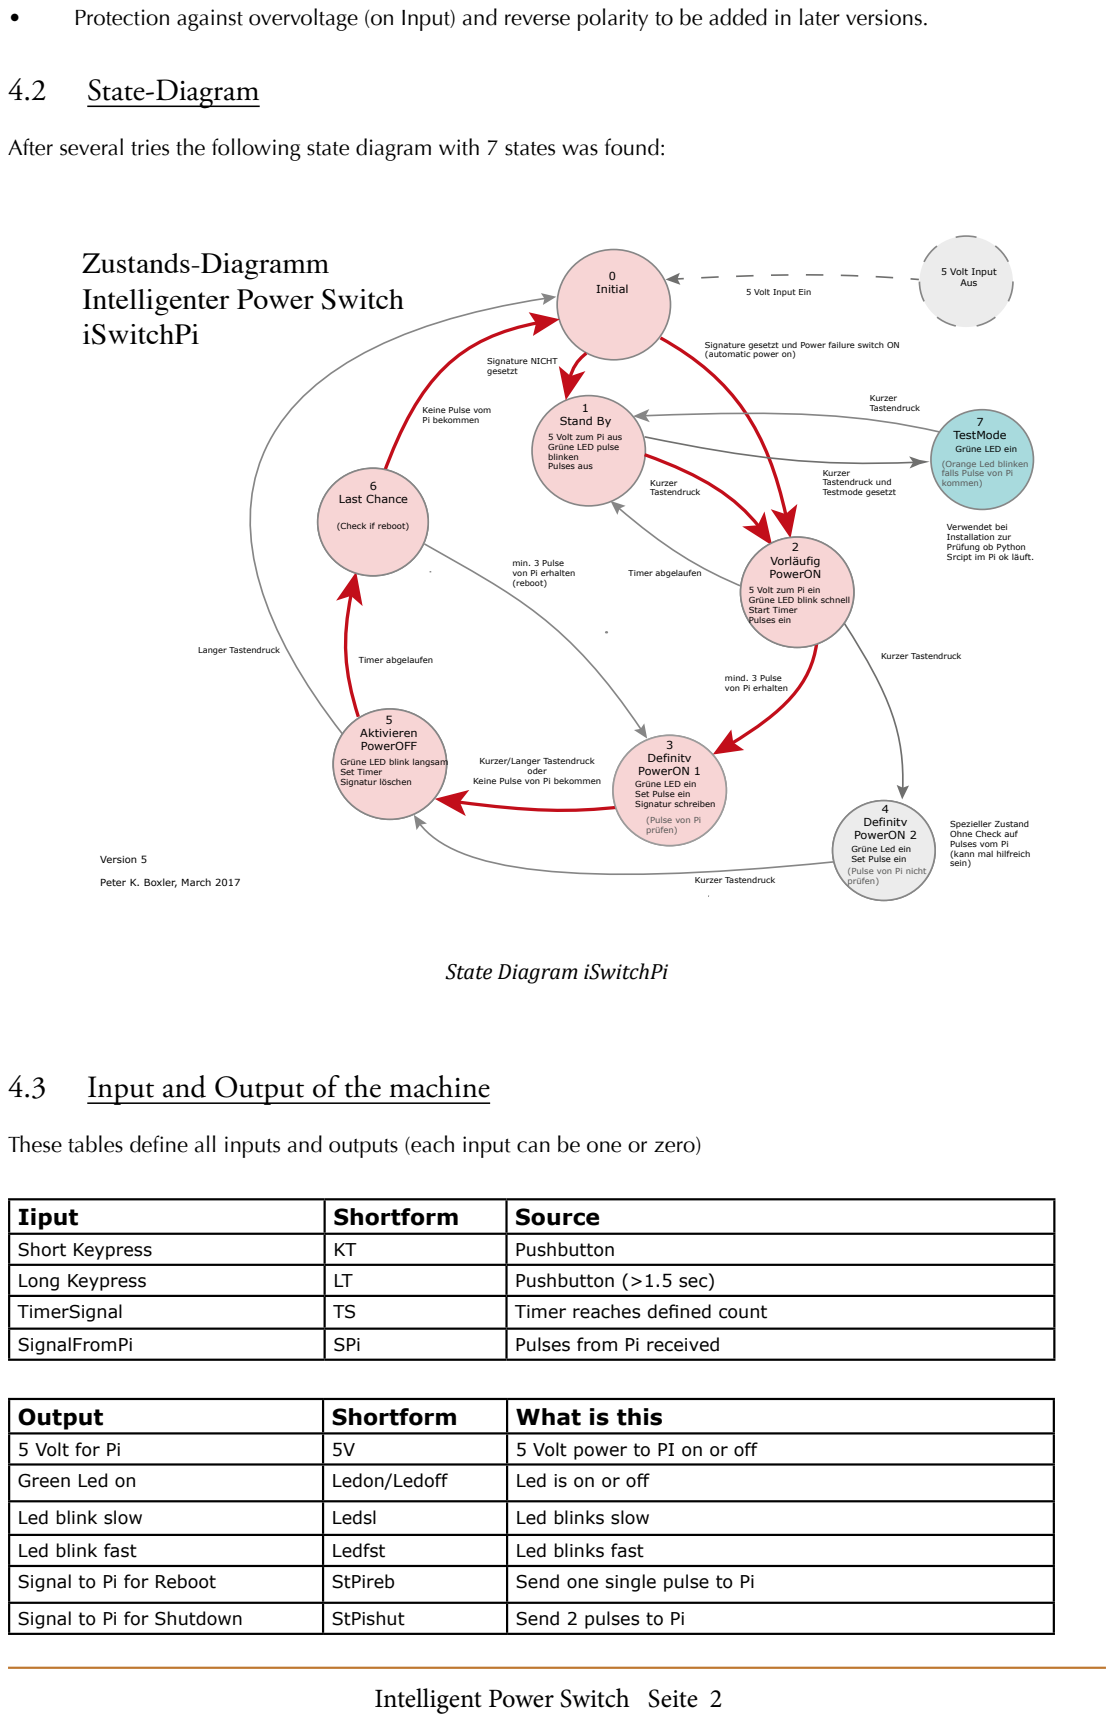
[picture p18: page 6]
0 Initial; 6 Last Chance; Kurzer Tastendruck; Kurzer Tastendruck und Testmode gesetzt; oder; Timer abgelaufen; Langer Tastendruck; 5 Volt Input Aus

• Protection against overvoltage (on Input) and reverse polarity to be added in later versions.

After several tries the following state diagram with 7 states was found:

Intelligenter Power Switch
iSwitchPi

5 Volt Input Ein

Signature gesetzt und Power failure switch ON

(automatic power on) Signature NICHT
gesetzt

Stand By
5 Volt zum Pi aus
Grüne LED pulse
blinken
Pulses aus

Keine Pulse vom
Pi bekommen

TestMode
Grüne LED ein
(Orange Led blinken
falls Pulse von Pi
kommen)

(Check if reboot)

Verwendet bei
Installation zur
Prüfung ob Python
Srcipt im Pi ok läuft.

Vorläufig
PowerON
5 Volt zum Pi ein
Grüne LED blink schnell
Start Timer
Pulses ein

min. 3 Pulse
von Pi erhalten
(reboot)

mind. 3 Pulse

Aktivieren
PowerOFF
Grüne LED blink langsam
Set Timer
Signatur löschen

Definitv
PowerON 1
Set Pulse ein
Signatur schreiben
(Pulse von Pi
prüfen)

Kurzer/Langer Tastendruck
Keine Pulse von Pi bekommen

PowerON 2
Grüne Led ein
(do not check on Pi)
(Pulse von Pi nicht

Spezieller Zustand
Ohne Check auf
Pulses vom Pi
(kann mal hilfreich
sein)

Version 5
Peter K. Boxler, March 2017

State Diagram iSwitchPi

4.3 Input and Output of the machine

These tables define all inputs and outputs (each input can be one or zero)

Iiput | Shortform | Source
Short Keypress | KT | Pushbutton
Long Keypress | LT | Pushbutton (>1.5 sec)
TimerSignal | TS | Timer reaches defined count
SignalFromPi | SPi | Pulses from Pi received

Output | Shortform | What is this
5 Volt for Pi | 5V | 5 Volt power to PI on or off
Green Led on | Ledon/Ledoff | Led is on or off
Led blink slow | Ledsl | Led blinks slow
Led blink fast | Ledfst | Led blinks fast
Signal to Pi for Reboot | StPireb | Send one single pulse to Pi
Signal to Pi for Shutdown | StPishut | Send 2 pulses to Pi

Start Timer | STo or STf | On /Off (means start/stop Timer)
Pulsgenerator | ON/OFF | Puls Generation ON/OFF

## 4.4 State Diagram

The state diagram describes the workings of finite state machine completely. The transfer to a c-program is simple. A certain state combined with a combination of input signals leads to a new state as shown in state diagram.

State | Inputs | Next State
| SK | LK | TS | SPi | TM
1 Stand by | 1 | x | x | x | x | 2 Tentative Power On
1 Stand by | 1 | x | x | x | 1 | 7 Test Mode
2 Tentative Power On | x | x | 0 | 1 | | 3 Power On-1
2 Tentative Power On | x | x | 1 | 0 | | 1 Stand by
2 Tentative Power On | 1 | x | x | x | | 4 Power On-2
3 Power On-1 | 0 | 0 | x | 0 | | 5 Activate Power Off
3 Power On-1 | 1 | 0 | x | 0 | | 5 Activate Power Off
3 Power On-1 | 0 | 1 | x | 0 | | 5 Activate Power Off
4 Power On-2 | 1 | x | x | x | | 5 Activate Power Off
5 Activate Power Off | x | x | 1 | 0 | | 1 Stand by
5 Activate Power Off | x | 1 | x | x | | 1 Stand by
6 Last Chance | x | x | x | 0 | | 1 Stand by
6 Last Chance | x | x | x | 1 | | 3 Power On
7 Test Mode | X | | | | | 1 Stand by

## 4.5 Activities upon entering a state

Every state of the machine usually has some entry-actions associated with this state. These actions are executed once upon entering the state and they usually result in changes in the outputs.

State | Activity on Input
1 Stand by | 5 Volt Power off Set Led to Pulse blink Timer stop Pulsgenerator stop
2 Tentative Power On | 5 Volt Power On Green Led blink fast Timer start Pulsgenerator start
3 Power on-1 (normal operation) | Green Led full on Timer stoppen
4 Power on-2 (spezieller Betrieb) | Green Led full on Timer stoppen
5 Activate Power Off | Green Led blink slow Timer start
6 Last Chance | nothing
7 Test Mode | 5 Volt Power On Green led full on

# 5. Component A: Electronics

The iSwitchPi implements the on / off function of the Pi power supply in software and hardware. The state diagram and the state tables define the c-program to be created for the ATtiny44. The Pi itself will send regular pulses by means of a script (see below), which signal: I am still alive, do not turn off the power.

## 5.1 Schema

The hardware component of the iSwitchPi is designed to be in the form of a raspberry hat. Usage is simple: stack on top of the Pi, connect a 5 volt power supply and you are ready to run. Additional hats can be stacked on top of the iSwitchPI.
The electrical scheme of the iSwitchPi looks like this.
5 Volt Power to the Pi is switched on/off with a High-Side Switch MCP2505. This clever device has a voltage drop of only around 15 mV in the ON state. It handles up to 2 Amps. It is controlled by the MCU. The input voltage of 5 V is reduced to 3.3 V for the microcontroller using a LM1171MP-3.3 module. Thus, the communication line for the Pi is also addressed with this level (GPIO pins for the Pi are rated 3.3 v max).
The Python script running in the Pi (iswitchpi.py) signals ‚I am alive‘ with pulses on a selected GPIO-Pin. The script can, however, also receive signals from the iSwitchPi on the same GPIO-Pin: the number of incoming pulses determine the type of the command which is sent to the OS: shutdown halt or reboot.
The heart of iSwitchPi is an ATtiny44 microcontroller.
C program (firmware) for the microcontroller, see later.

Note:
Future version of the iSwitchPi need to include a protection against wrong polarity and overvoltage. This will be the same circuit as on the Raspberry board. See this text for details:
Raspberry voltage protection. (https://learn.adafruit.com/introducing-the-raspberry-pi-model-b-plus-plus-differences-vs-model-b/power-supply)


Schema iSwitchPi

## 5.2 Printed Circuit Board

The output of the Eagle PCB program is a board-file. This file is sent to (in my case) to
Eurocircuits (http://www.eurocircuits.de)
and this company will fabricate the printed circuit board. The first batch of 10 prototype boards cost about 90 Euros. Notes on the board:
The Attiny sits in a 14-pol socket. There is no ICSP-Connection on the board and the MCU is plugged from the socket if reprogramming is needed.


PCB iSwitchPi

## 5.3 Puls Generator

In addition to the on-off switching functionality, the iSwitchPi circuit also supplies a variable frequency square wave (Duty Cycle ca. 10%). This can be used to interrrupt the Pi for other purposes.

- fixed frequencies selectable with dip-switch 0.2/0.5/1/5/10/50/100/500 Hz
The GPIO-Pin is also selectable with a 4-pos dip-switch. GPIO-Pins 17,22, 23 or 27 are available.

## 5.4 Communication between Pi and Electronic

The Python script described below basically creates a 50ms pulse on the defined GPIO pin every second. These pulses signal to the iSwitchPi: I am still alive. That GPIO-PIn is routed to an input pin on the ATtiny44.
The program in ATtiny44 is always listening on that input, in order to receive these pulses. If no pulses are received, it is assumed that the Pi is no longer running or is in a reboot process. The power-off sequence is then initiated.
If the pushbutton is pressed (short or long for shutdown or reboot, respectively), the Attiny sends pulses to the Pi (on the same line): one pulse means shutdown, two pulses are reboot.
These pulses, however, are sent only after a pulse from the Pi has arrived - only at this point in time it is known that the Pi is listening.

The following scheme will illustrate the communication between Python script and c-program in the ATtiny44.

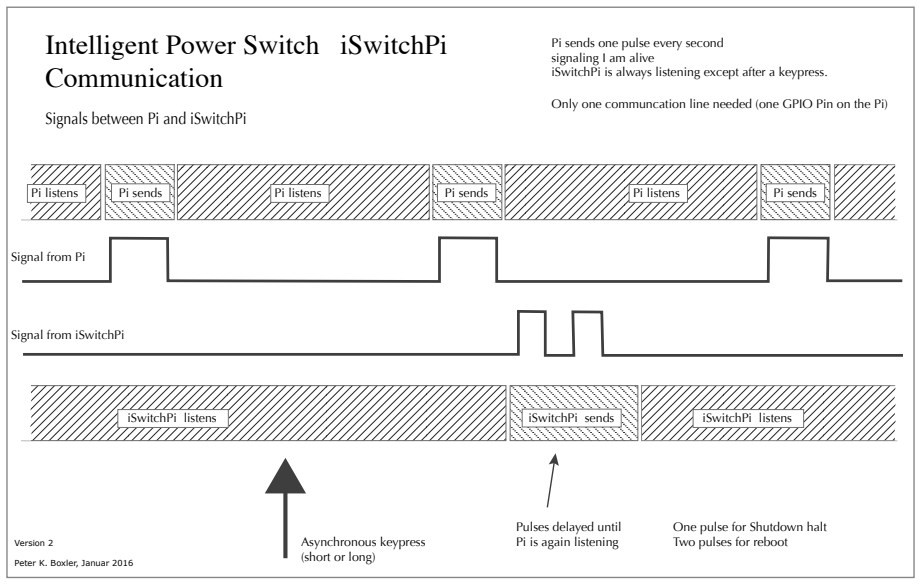
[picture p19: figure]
Version 2; Peter K. Boxler, Januar 2016; Intelligent Power Switch iSwitchPi Communication; iSwitchPi listens; iSwitchPi sends; Signal from Pi; Signal from iSwitchPi; Signals between Pi and iSwitchPi; Pi sends one pulse every second signaling I am alive; Asynchronous keypress (short or long); Pulses delayed until Pi is again listening; One pulse for Shutdown halt Two pulses for reboot; Pi listens; Pi sends

iSwitchPi is always listening except after a keypress.

Only one communcation line needed (one GPIO Pin on the Pi)

Comunication

## 5.5 C-Program for ATtiny44

The executable for the Attiny44 is compiled/linked from two C programs:

- Implementation of the Finite State Machine with 7 states (iswitchpi.c)
- Implementation of the puls generator using Timer 1 (square.c)
The use of the I/O pins of the ATtiny is documented in the source code. The C program implements the finite machine with 7 states according to the state table. The push button for triggering the various functions is debounced with C code by Peter Dannegger. His code is published and discussed on Mikrocontroller.net. It works great, but is not easy to understand. I added an additional key_clear () function. This makes it easier to synchronize the push-button with the states. The ATtiny44 needs to run at 1 Mhz, the Makefile specifies this clock frequency. So make sure the fuses are set to 62 DF FF (default values).
There are also good tutorials for programming AVR microcontrollers in Mikrocontroller.net.
The code of the C program is available on GitHub
Flashing the executable to the ATtiny44 see further down.

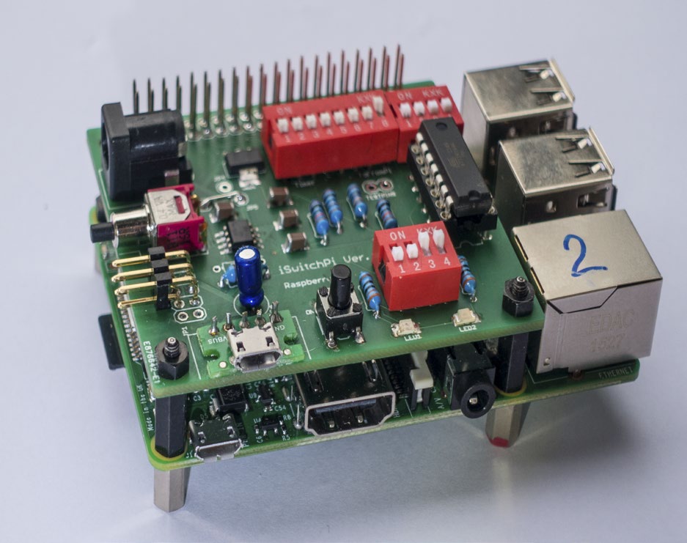
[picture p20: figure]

iSwitchPi stacked on a Pi 2 Modell B

# 6. Component B: Python Shutdown Script

The electronics communicates with a small Python script that is running in the Pi. That script is started at boot time (Entry in /etc/rc.local).
The clever thing here is that only on GPIO-Pin is used for this 2-way communication. See comm-diagramm for details.
The Python script is started at boot time with the follwing line added to /etc/rc.local. (replace folder myservices with your own folder within pi home:

python /home/pi/myservices/iswitchpi.py [-d N] [-p nn] &
Two commandline parms are accepted: -d for debugoptions and - p for selection of GPIO Pin used. Both are optional.
- 0: No debug uutput (quiet)
- 1: simple debug out, is default value
- 2: Full debug output for testing.
Commandline parm -p specifies the GPIO pin to be used for communication with the iswitchPi board. This must correspond to the Pin selected with the dip-switch on the board!
- no parm -p: by default GPIO-Pin 20 is used.
- Possible values (pins) - p 13 or - p 19 or -p 26 or- p 20

# 7. GPIO Pins used

Only one GPIO pin is required for the basic function of the iSwitchPi (Power On / Off). If you want to use the Pulse function, a second GPIO pin is necessary.

- Communication between the iSwitchPi board and the pythonscript iswitchpy.py in the Pi. The desired pin number is selected on the board using the 4-pol. dip switch, GPIO pins 13, 19, 20 and 26 are available. The pin must also be defined in the Pythonscript. By default, the script uses the pin GPIO 20 (physical pin number 38). A different (above-mentioned pin) can be defined by means of the command line parameter -d. See above.
- If the pulse function of the iSwitchPi board is used, a further GPIO pin is necessary. The desired pin number is selected on the board by means of the 4-pol. pip switch. GPIO pins 17, 22, 23 and 27 are available. Use the same pin in your script that uses the interrupt.

# 8. Install iSwitchPi

Read the Quick Start Guide to iSwitchPi (English und German). The document details the installation procedure. Note
Install starts with installing the Python script iswitchpi.py in the Raspberry Pi. This script needs to run ok prior to stacking the board onto the Pi. However, without an oscilloscope is it somewhat difficult to see whether the pulses sent from the script reach the correct GPIO pin on the board. For this reason, the board can be put in TestMode by setting dip-switch 4, position 1 to ON. In this mode the board acts as a visualizer to check the pulses. Only if the pulses are verified the board will work ok.
Check out the Quick Start Guide.

# 9. Test Setup

This is the breadboard use to develop iSwitchPi.


Test Setup iSwitchPi on a Breadboard (ohne Pi)

# 10. Programming the ATtiny44

I developed the code for iSwitchPi on a Mac. The toolchain used is CrossPack for AVR Development (https://www.obdev.at/index-de.html) .
This package installs the following components:
- tThe compiler avr-gcc with all the neccesary libraries

- The Commandline-Uploader AVRDUDE
I built a small board with a zero-force socket to flash the MCU. This board connects to the programmer Olimex AVR-ISP-MK2 with itself is connected to the Mac with a USB cable.
Flashing is done with uploader AVRDUDE - the makefile does this with the command make flash.


Programmer for ATtiny44

Note zu CrossPack Version:
On a Mac OSX 10.9 (and higher) one needs to install AVRDUDE Version 5.11.1. Version 6.01 does not work with Olimex ISPMK2. Check out these discussions: http://www.avrfreaks.net/forum/olimex-isp-mk2-error-mac-osx-109http://www.avrfreaks.net/comment/1011406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

That is why I have installed CrossPack-AVR-20121203.

# 11. Components on the PCB

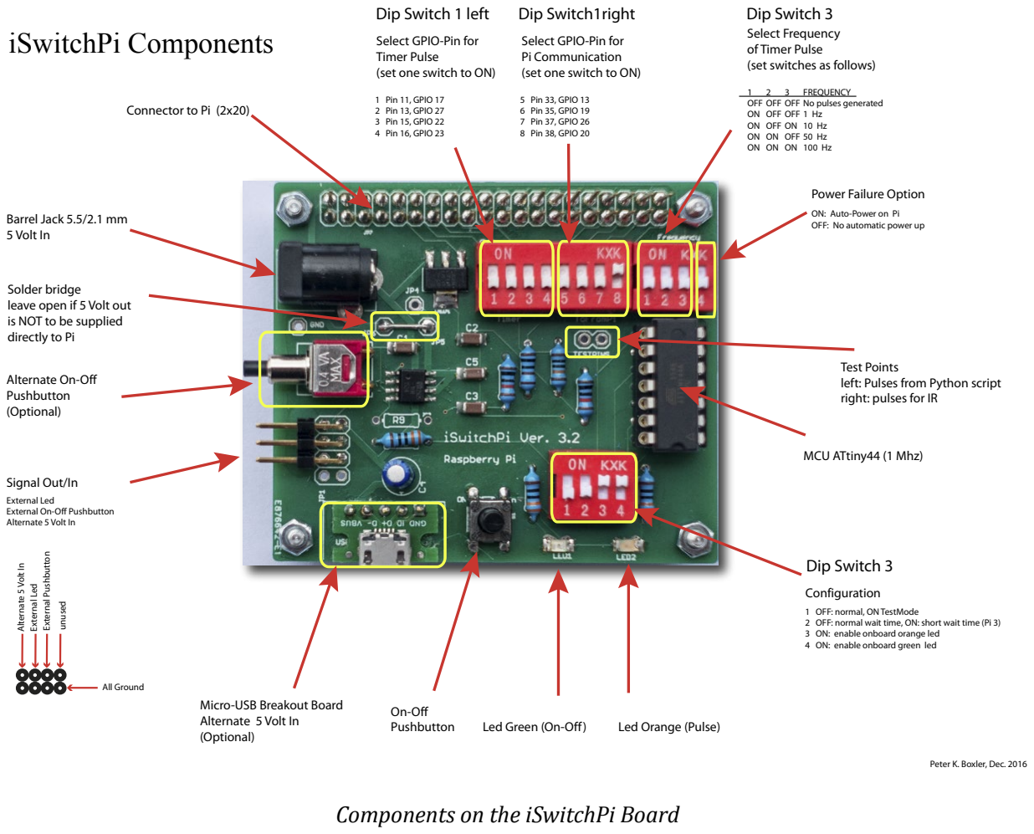
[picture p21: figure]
Led Green (On-Off); Micro-USB Breakout Board Alternate 5 Volt In (Optional); Signal Out/In; Barrel Jack 5.5/2.1 mm 5 Volt In; Solder bridge leave open if 5 Volt out is NOT to be supplied directly to Pi; Connector to Pi (2x20); Peter K. Boxler, Dec. 2016 updated March 2017; Test Points left: Pulses from Python script right: pulses for IR; Led Orange (Pulse); iSwitchPi Components; MCU ATtiny44 (1 Mhz); On-Off Pushbutton; Alternate On-Off Pushbutton (Optional); Select GPIO-Pin for Pi Communication (set one switch to ON); 5 Pin 33, GPIO 13 6 Pin 35, GPIO 19 7 Pin 37, GPIO 26 8 Pin 38, GPIO 20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

2 OFF: normal wait time, ON: short wait time (Pi 3)

# 12. Conclusion

The attempt to formulate the problem description by means of a Finite State Machines has cost a lot of effort, but has made the solution much clearer. Writing the C program was relatively simple since state diagram and the state tables define everything. There were no serious logical problems with the program flow during testing.
What again confirms the old truth of sytems engineering; think first, code later.

# 13. Updates

In April of 2017 an update was made to the firmware in the ATtiny44. A user requested an auto-power-on functionality: the Pi should restart unattended (meaning without the need to press the ON-pushbutton) when 5 Volt comes back after a power failure. State 0 was added to the state diagram and position 4 of dip-switch 3 is used to select/ deselect this feature.

# 14. Links

My Raspberry Projects
Projekt-Website (http://projects.descan.com)

Source Code iSwitchPi incl. Eagle Files GitHub (https://github.com/dakota127/iswitchpi)

Other Links
Initial State Raspberry Pi GPIO Pins Raspberry Foundation (https://www.raspberrypi.org/documentation/configuration/pin-configuration.md)

About Finite State Machines http://www.mikrocontroller.net/articles/Statemachine

Tutorials for AVR Mikrocontroller http://www.mikrocontroller.net/articles/AVR-Tutorial

Eagle PCB Design Software
http://www.cadsoft.de

The Best Resource on the Web

## https://www.adafruit.com

In der CH zu empfehlen, führt Adafruit Produkte http://www.play-zone.ch

# 15. Attachments

## 15.1 Example Scripts für iSwitchPi

Folder sources/examples on GitHub contains 2 Python Scripts, one of which shows how the square-wave output of iSwitchPi can be used in a Python script with an interrupt handler.

- Script example-interrupt.py shows, how a led can be blinked using an interrupt-handler. This, of course, can be done without interrupts but having an external source for periodic interrupts make this easy.
- Script example-sighandler.py shows how to gracefully terminate a Python script - eg. after ctrl-c or a kill signal is used. Sometimes on wishes to reset GPIO pins before terminating. This is one way of doing it.

## 15.2 Parts List iSwitchPi

Part | Value | Package | Note | Supplier | PartNumber

Condensator
C1 | 1uF | SMD1206 | ceramic | Any
C2 | 1uF | SMD1206 | ceramic | Any
C3 | 1uF | SMD1206 | ceramic | Any
C4 | 1uF | E2,5-6E | | Any
C5 | 1uF | SMD1206 | ceramic | Any

IC
IC1 | MCU ATTINY44 | DIL14 | Attiny
IC2 | MIC2025-1YM | SO08 | High-Side Switch
LM117 | LM1171MP-3.3 | SOT223 | 3.3 Volt Regulator | Distrelec | 110-38-693

Led
LED1 | green | SMD 1206 | SMD 1206
LED2 | orange | SMD 1206 | SMD 1206

Resistor
R1 | 100k | 0204/7 | Any
R2 | 10k | 0204/7 | Any
R3 | 320 | 0204/7 | Any
R4 | 320 | 0204/7 | Any
R6 | 10k | 0204/7 | Any
R7 | 320 | 0204/7 | Any
R8 | 1k | 0204/7 | Any
R9 | 80 | | | Nur bei MIC2445A

DIP-Switch
S2 | DIP04S | Dip 4-Pol | Any
S3 | DIP08S | Dip 8-Pol | Any
S4 | DIP04S | Dip 4-Pol | Any

Pin Header
J1 | | 1X02 | Onboard green Led On/Off
J2 | | 1X02 | without Pi
JP1 | | 2X04 | Input/Output
JP3 | | 1X01 | Optional 5 V IN
TestPins | | 1X02 | TestPins
JP5 | | 1X01 | 5 V to Pi, connect to JP6
JP6 | | 1X01 | 5 V to Pi, connect to JP5
JP7 | extra long pins | 2X20-BIG | GPIO Stacking Header | Adafruit | 2223

Pushbutton
S1 | 6x6 mm | B3F-10XX | Pushbutton On/Off | Adafruit | 367/1490/ P00000256 P00000681

Other
IC-Socket 14-pol | for ATtiny44 | Any

5 Volt IN
PB3 | 2.1MMJACK | Barrel Jack 5.5/2.1 mm | Adafruit | 373
PB4 | ADAUSBMICRO | USB-Micro-Brea-kout | Adafruit, Play-Zo-ne | 1833/P00001025

Only if High-Side Switch is MIC 2445A

R8 | 80 | 0204/7 | Any

Optional, second
Pushbutton On/Off

PB1 | Button liegend | Pushbutton On/Off | Distrelec | 135-75-923 off-(on) 1P, 6A52- F4H9AE, Eledis

Montage
| Standoff | 4 Pieces | 11mm/2.5mm | Adafruit | 2336

## 15.3 Code iSwitchPi

A snippet of the c-code implementing the Finite State Machine:

// ---- Main Loop. forever ---------------------
// ---- Implements State Machine ---------------
for(;;)
{
// | _delay_ms(10); | // for testing

switch (state) {
/*------------------------------------------------------------------*/
/* | state 0 | Initial State State | */
/* | is entered upon 5 Volt Power on | */
/* | check if Pi auto power-on is selected | (dip Switch) | */
/* | if NO --> goto state 1 | */
/* | if YES --> goto state 2 | */
/*------------------------------------------------------------------*/ case state0:
if (first_time & (1<<STAT0_FIRST)) { | // first_time time throu ?
first_time =0xff; | // set first_time all other states
first_time &= ~(1<<STAT0_FIRST); | // clear first_time this state
}
tick2=0;
pastpulses=0; | // pulse counter reset (pulses from Pi)
if ( !(PINB & (1<<AUTO_POWER)) ) | // check if auto power on is required (dip switch Pos 4 ON)
state=state2; | // if YES: next state is state 2
else
state=state1; | // if NO: next state is state 1

break;

/*------------------------------------------------------------------*/
/* | state 1 | Stand-by State, all is off, waiting for short keypress | */
/* | Power to Pi ist off, led blinks short pulses | */
/* | Waiting for short keypress | */
/*------------------------------------------------------------------*/
case state1:
if (first_time & (1<<STAT1_FIRST)) { | // first_time time throu ?
PORTA &= ~( 1<<LED1 | 1<<VPOWER); | // all outputs off
key_clear( 1<<KEY0 );
blinkwhat=PULSED_Blink;
tick2=0;
blinkon=1;
pwm_stop(); | // stop pulse genaration
output on PA5
pastpulses=0; | // pulse counter reset (pulses from Pi)
first_time =0xff; | // set first_time all other states
first_time &= ~(1<<STAT1_FIRST); | // clear first_time this state
}
if (get_key_short( 1<<KEY0 )) { | // get debounced keypress
if (!(PINA & (1<<TESTPIN)) ) | // if Testpin is low: signalling TESTMODE
state=state7; | // next state is state 7
else
state=state2; | // next state is state 2
} | // leaving standby
break;

/*------------------------------------------------------------------*/
/* | state 2 | Tentative Power on, waiting for Pi to come up | */
/* | Power to Pi ist on, led is blinking fast | */

/* | Short keypress switches to state 4 | (power on without checking */
/* | whether Pi is on) | */
/*------------------------------------------------------------------*/ case state2:
if (first_time & (1<<STAT2_FIRST)) { | // first_time time throu ?
PORTA |= (1<<VPOWER); | //switch 5 volt power on
poweron_delay=POWERON_Delay_long;
if ( !(PINA & (1<<DELAYTIME)) ) {
poweron_delay=POWERON_Delay_short; | // check pin PA6 for delay times (Dip-
switch 4 Pos 2 ON)
}

blinkwhat=REGULAR_Blink;
blinkint=POWERON_Blink_int;
tick2=0; | //start timer
sekunde=0;
pwm_start(); | // start pulse generati-
on output on PA5
first_time =0xff; | // set first_time all other states
first_time &= ~( 1<<STAT2_FIRST); | // clear first_time this state
}

pwm_check();

if ((blinkwhat>0) && (sekunde > poweron_delay)) {
blinkwhat=0;
state=state1; | // Pi did not come on, so gaback to stand by
}
if (get_key_short( 1<<KEY0 )) | { | // get debounced keypress short
blinkwhat=0;
state=state4;
}
// how many pi pulses have we received ? if we have Pi is alive // so we go to state 3 (normal operation state)
if (pastpulses > 3) {state=state3;}

break;

/*------------------------------------------------------------------*/
/* | state 3 | Power ON Number 1, regular operating state | */
/* | Power to Pi ist on, led is on | */
/* | Loss of signal from Pi changes state to 5 | */
/* | Short keypress | signals Pi to shut down, changes state to 5 | */
/* | Long Keypress signals Pi to reboot, stays in state 3 | */
/*------------------------------------------------------------------*/ case state3:
if (first_time & (1<<STAT3_FIRST)) | { | // first_time time throu ?
PORTA |= (1<<LED1); | // led full on
blinkwhat=0;
key_clear( 1<<KEY0 );
first_time =0xff; | // set first_time all other states
first_time &= ~( 1<<STAT3_FIRST); | // clear first_time this state
}
pwm_check(); | // check various inputs for frequency of
pulse on PA5
if (get_key_short( 1<<KEY0 )) { | // get debounced keypress short
cli();
sendnow=1; | // set flag so IR handler can send signal
sei(); | // Interrupt enable
state=state5; | // next state 5
poweroff_delay=POWEROFF_Delay_HALT_long; | // Poweroff delay for halt
if ( !(PINA & (1<<DELAYTIME)) ) {
poweroff_delay=POWEROFF_Delay_HALT_short; | // check pin PA6 for delay times (Dip-
switch 4 Pos 2 ON)
}

}

if( get_key_long( 1<<KEY0 )) | { | // get debounced keypress long
cli();
sendnow=2; | // set flag so IR handler can send signal
sei(); | // Interrupt enable
state=state5; | // next state 5
// Pi will reboot
poweroff_delay=POWEROFF_Delay_REBOOT_long; // Poweroff delay for halt
if ( !(PINA & (1<<DELAYTIME)) ) {
poweroff_delay=POWEROFF_Delay_REBOOT_short; // check pin PA6 for delay times (Dip-switch 4 Pos 2 ON)
}

}

// check numer of pulses from Pi, zero means: Pi is not alive
if (pastpulses < 2 ) | {
state=state5; | // ok, start power off sequence
poweroff_delay=POWEROFF_Delay_HALT_long; | // Poweroff delay for halt
}
break;

/*------------------------------------------------------------------*/
/* | state 4 | Power ON Number 2, special operating state | */
/* | we do not care about pulses from Pi | */
/* | Power to Pi ist on, led is on | */
/* | Short keypress | signals Pi to shut down, changes state to 5 | */
/*------------------------------------------------------------------*/ case state4:
if (first_time & (1<<STAT4_FIRST)) { | // first_time time throu ?
PORTA |= (1<<LED1); | // led full on
blinkwhat=0;
key_clear( 1<<KEY0 ); | // ignore keypresses that might have come
first_time =0xff; | // set first_time all other states
first_time &= ~( 1<<STAT4_FIRST) | ; | // clear first_time this state
}
pwm_check(); | // | Pulse generation
// | Check DIP-Switch (PINB0 to PINB2)
if (get_key_short( 1<<KEY0 )) | { | // get debounced keypress short
cli();
sendtopi(1); | // set flag so IR handler can send signal
sei(); | // Interrupt enable
state=state5;
_delay_ms(10);
poweroff_delay=POWEROFF_Delay_HALT_long; // Poweroff delay for halt

}
break;

/*------------------------------------------------------------------*/
/* | state 5 | Activate Power off, prepare to shut off | */
/* | irrelevant of signals from Pi | */
/* | Power to Pi ist still on, led is blinkng slow | */
/* | Short keypress | changes to state 4 (keep power on regardless | */
/* | of signal from Pi) | */
/* | Long keypress switches off immediately (goto state 1) | */
/* | goto stand by state if timer runs out | */
/*------------------------------------------------------------------*/ case state5:
if (first_time & (1<<STAT5_FIRST)) | { | // first_time time throu ?
blinkwhat=REGULAR_Blink; | // set led to blink
blinkint=POWEROFF_Blink_int;
key_clear( 1<<KEY0 ); | // ignore keypresses that might have come
pastpulses=0;
tick2=0; | //start timer
sekunde=0;
first_time =0xff; | // set first_time all other states
first_time &= ~( 1<<STAT5_FIRST) | ; | // clear first_time this state
}
// | pwm_check(); | // | Pulse generation
// | Check DIP-Switch (PINB0 to PINB2)
if (get_key_short( 1<<KEY0 )) { | // get debounced keypress short
state=state3;
}
if( get_key_long( 1<<KEY0 )) | { | // get debounced keypress long
state=state1; | // next state 5
// Pi will reboot
}

/* removed this - not in state diagram
// check Signal from Pi, how many pulses have we received
if (pastpulses > 4) | { | // Pi seems to ba alive, ok keep power on
state=state3;
}
*/
// wait for POWEROFF_Delay sec before switching off 5 Volt supply if ((blinkwhat>0) && (sekunde > poweroff_delay)) {
blinkwhat=0;
state=state6; | // next state is state 5
}

break;
/*------------------------------------------------------------------*/

/* | state 6 | Last Chance | (check if Pi rebooted) | */
/* | we are about to switch 5 Volt power off | */
/* | but before we do that we check the signal from Pi again : | */
/* | If further pulses came in (Pi rebooted) we keep power on | */
/* | If no more pulses came in we go to state 1 | */
/*------------------------------------------------------------------*/
case state6:
first_time =0xff; | // set first_time all other states
key_clear( 1<<KEY0 );

// check Signal from Pi
if (pastpulses > 3) | {
| | state=state3;
}
else state=state1;
| break;

/*------------------------------------------------------------------*/
/* | state 7 | TESTMODE only | | */
/* | Power to Pi is switched on, green led is on | */
/* | Orange Led blinks every 3 seconds IF and only if pulses from Pi */
/* | are ok received. | */
/* | Short keypress: next state is state1 (off) | */
/*------------------------------------------------------------------*/ case state7:
if (first_time & (1<<STAT7_FIRST)) | { | // first_time time throu ?
PORTA |= (1<<VPOWER); | //switch 5 volt power on
PORTA |= (1<<LED1); | // led full on
| | blinkwhat=0;
key_clear( 1<<KEY0 );
| | tick2=0; | //start timer
| | sekunde=0;
| | blink_led();
| | first_time =0xff; | | // set first_time all other states
first_time &= ~( 1<<STAT7_FIRST) | ; | // clear first_time this state
}
if (get_key_short( 1<<KEY0 )) { | // get debounced keypress short
| | state=state1;
}

// check Signal from Pi blink orange led when 2 pulses have been received
if (pastpulses > 2) | {
| | blink_led();
pastpulses=0;
| | }
| }
//---- | End of Switch Statement -----------------------------

Ende des Dokumentes.

Peter K. Boxler, Februar 2016 Updated April 2017

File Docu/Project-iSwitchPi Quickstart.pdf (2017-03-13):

# Quick Start Guide iSwitchPi

# Intelligent Power Switch for Raspberry Pi

English and German Version

### Quick Start Guide Intelligent Power Switch Seite 3

Inhaltsverzeichnis

# Quick Start Guide to iSwitchPi (English)

## 1. Board Overview

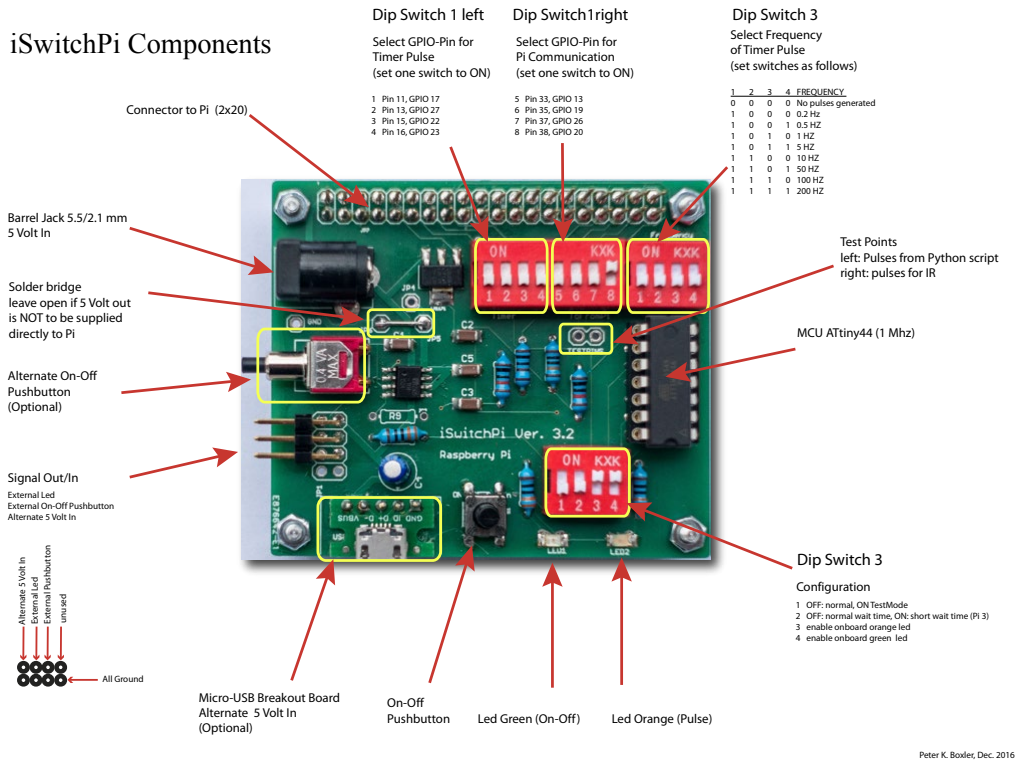
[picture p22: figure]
Led Green (On-Off); Micro-USB Breakout Board Alternate 5 Volt In (Optional); Signal Out/In; Barrel Jack 5.5/2.1 mm 5 Volt In; Solder bridge leave open if 5 Volt out is NOT to be supplied directly to Pi; Connector to Pi (2x20); Peter K. Boxler, Dec. 2016; Test Points left: Pulses from Python script right: pulses for IR; Led Orange (Pulse); iSwitchPi Components; MCU ATtiny44 (1 Mhz); On-Off Pushbutton; Alternate On-Off Pushbutton (Optional); Select GPIO-Pin for Pi Communication (set one switch to ON); 5 Pin 33, GPIO 13 6 Pin 35, GPIO 19 7 Pin 37, GPIO 26 8 Pin 38, GPIO 20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

2 OFF: normal wait time, ON: short wait time (Pi 3)

Board Overview with Default Switch Settings

## 2. Before you start

Make yourself familiar with the layout of iSwitchPi-Board shown above.
Preferably, start with the default switch settings.

Before installing the iSwitchPi board you have to define a GPIO pin to be used for communication. This is called the GPIO communication pin. The design of the board allows you to choose between the fol-lowing GPIO pins: 13,19,20 or 26 (corresponding to physical pins 33,35,37 and 38). If you already use these pins in your application you need to redesign it to make one of these pins available.
If possible, use GPIO pin 20 since this is the default value.
Furthermore, if you plan to use the square wave output of the iSwitchPI board as an external interrupt line to the Pi you need to choose another GPIO pin for the interrupt signal. For this, the design of the board allows you to choose between these GPIO pins: 17,22, 23, or 27 (corresponding to physical pins 11,15,16 and 13). This is called the GPIO interrupt pin.
Take a note of both pin numbers, you will need them during installation.
Also locate the Python script iswitchpi.py that needs to be transferred to the Pi later on. You can find the script (and the full documentation) on GitHub. (https://github.com/dakota127/iSwitchPi) Download the repository to your local machine. Locate the script in this folder ../sources/python.

## 3. Overview Installation

The Installation is done in several steps:
- Define the GPIO pins you intend to use for iSwitchPi.
- Install the Python script in the Pi and make sure it is running ok by checking the console messages during boot.
- Stack the board onto the Pi, set the dip-switches and use the board in TestMode - this allows you to actually test the GPIO communication pin.
- Disable TestMode and have fun using this clever device.

Warning: Do not connect a 5 Volt Power supply to the Pi while using the iSwitchPi board! Power to the Pi is supplied from the board.

## 4. Installation Details

After defining the GPIO pins to be used, follow these steps to get your iSwitchPi board up and running. Again, for best results use GPIO Pin 20 (Pin Number 38) for the GPIO communication pin. This is the default pin used in the Python Script.

## 4.1 Install the iSwitchPi Python script in the Pi

- Connect a power supply to the Micro USB connector on the Pi board. Make sure you run the Pi without the iSwitchpi board at this stage.
- Login to the Pi and create a folder in the home folder of user pi. Call this folder iswitchpi or any other name you can remember.
- Copy the Python script iswitchpi.py into this folder. Use your preferred method to do this.
- Edit the file /etc/rc.local and add a line to start this script at boot time (replace myfolder with your folder name)

python /home/pi/myfolder/iswitchpi.py &
If you want to specify a GPIO pin other than the default (GPIO 20) use commandline parms:
- python /home/pi/myfolder/iswitchpi.py [-d N] [-p nn] &

The commandline parameter -d specifies debug output (default is 1):
- 0: no output (quiet)
- 1: output at start and when a shutdown comand is issued (HALT oder REBOOT) (default)
- 2: full debug output for testing.

The commandline parameter -p specifies the GPIO communication pin:

- no parameter -p: GPIO 20 is used by default (physical pin 38).
- choose between - p 13 or - p 19 or -p 26 or - p 20
- Reboot the Pi and connect a display to the HDMI output. Check the boot messages and make sure the messages from script iswitchpi are visible. Check the output and make sure the script reports the correct GPIO pin it will use. This confirms that the script is running properly. Later, you can check if the board receives the pulses from the Pi (use the boards TestMode).
- Shutdown the Pi with sudo halt.
- The Pi is now ready for the board.

## 4.2 Configure the board

- Stack the board onto the Pi but do not connect a power supply just yet.

Configure the board - communication Line
- The GPIO communication pin you defined previously (either 13,19, 20 or 26) needs to be set on Dip-Switch 1 right part. This must be the same pin the Python script uses.
- put ONLY ONE switch into position ON - thereby selecting GPIO 13,19,20 or 26
- Double check the pin number with what you selected on the commandline for the Python script. Make sure it is the same pin ! The script uses GPIO pin 20 if no commandline parm is given.

Configure the interrupt line (pulses)
- If you want to interrupt the Pi using the square wave output of the board you need to do the follo-wing:
- Locate Dip-Switch 2 on the board. Select the desired frequency by setting the 4 switches as indicated on the component diagramm. If you do NOT need the interrrupt line put all 4 switches in the OFF position - that disables the generation of the square wave.
- Locate Dip-Switch 1 left part on the board. This selects the GPIO interrupt pin. Put ONLY one switch into the ON position - thereby selecting GPIO 17,22,23 or 27
- Double check the pin number with what you use in your own interrrupt handling script. Make sure it is the same pin! A working example of an interrrupt-handling script can be found in the example folder.
- If you do NOT need the interrrupt line put all 4 switches of Dip-Switch 2 and Dip-Switch 1 left part into the OFF position.

External led and/or pushbutton
- If needed, connect an external led and/or external pushbutton to the 4x2 pin-header as indicated on the component diagramm. No resistor is needed for the led. You might want to do this if the Pi is in a box.

## 4.3 Check if the board receives pulses from Pi

This step helps you to find out if the pulses from the Pi are received by the board.
Put the board into the TestMode - set Dip Switch 3 position 1 to ON
- Connect a 5 Volt power supply to one of three possible inputs on the iSwitchPi board:
- Barrel Jack 5.5/2.1 mm - make sure that the polarity i ok: center pin is +5Volt. There is currently no protection against reverse polarity. So double check the polarity. The 5 Volt + is on the center pin of the barrel jack.
- Micro-USB connector
- 4x2 pin-header as indicated on the component diagramm. Again: check the polarity.

Pressing the pushbutton once powers the pi, green led is on and the orange led blinks just once. Wait until the Pi has booted and the Pyton scripts starts sending pulses. Watch the orange led - it should blink every 5 seconds or so. This tells you: ok, pulses from Pi are coming. If orange led does not blink check the GPIO communication pin used by the script and also check Dip switch 1 right part.

Another press on the pushbutton cuts power to the Pi. Clear the TestMode by setting Dip Switch 3 position 1 to OFF.

## 4.4 Using the board

Warning: Do not connect a 5 Volt Power supply to the Pi while using the iSwitchPi board! Power to the Pi is supplied from the board.

If everything is ok you should see the green led flash every second for 50 ms. That indicates the stand-by mode of the iSwitchPi. Your lucky: your are ready to start the Pi.

Note: if you are using a Pi 3 (which boots pretty fast) you might choose to set dip switch 3 position 2 to ON. If in doubt, put this switch OFF. This switch defines the wait time for the Pi to come up ( ON: short, OFF long).

A short press on the pushbutton should result in this:
- Th Pi will receive its 5 Volt power and will start to boot.
- The green led will blink fast. This indicates: ok, I have given power to the Pi and I am now waiting for the Python script to send pulses on the chosen communication line telling me that the Pi is running.
- If 3 pulses are received from the Pi the led will turn steady on. This indicates normal operating mode. If no pulses are received from th Pi (script not running or wrong GPIO communication pin configured) power to the Pi will be cut after 30 seconds.

Shutting down the Pi
- A short press on the pushbutton during normal operating mode will result in this:
- The green led starts to blink slow and the 20 sec power off timer ist started
- The Python script will be notified (using the GPIO communication line) and it will issue a sudo halt command. The Pi will shut down within 10 sec (on a Pi model 2 or 3).
- After the timer on the board (within the MCU) expires 5 Volt power will shut of. The led will go back to short pulse blinking - the stand by mode.

Study the state diagram to find out excactly what modes are possible.

Happy computing with the clever iSwitchPi.

# Quick Start Guide to iSwitchPi (German)

to be done.

End of document.

Peter K. Boxler, March 2017

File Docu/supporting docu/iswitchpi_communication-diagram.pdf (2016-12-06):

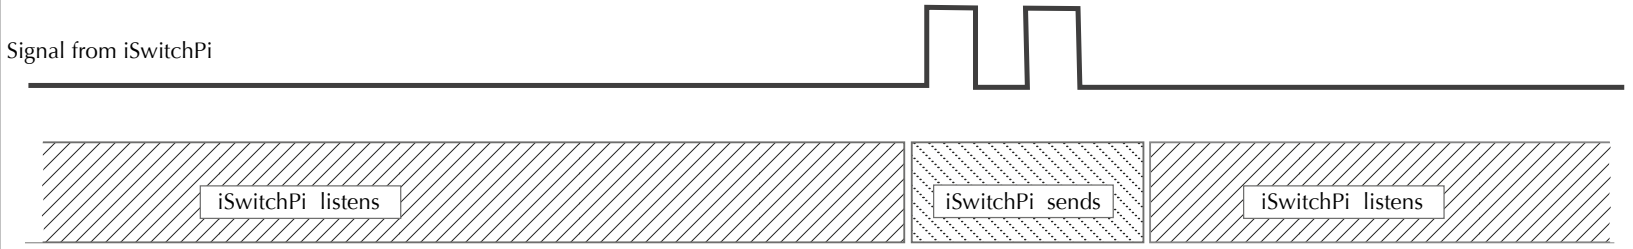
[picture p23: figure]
iSwitchPi listens; iSwitchPi sends; Signal from iSwitchPi

Version 2

Peter K. Boxler, Januar 2016

# Intelligent Power Switch iSwitchPi Communication

Signal from Pi

## Signals between Pi and iSwitchPi

Pi sends one pulse every second
signaling I am alive
iSwitchPi is always listening except after a keypress.

Only one communcation line needed (one GPIO Pin on the Pi)

Asynchronous keypress
(short or long)

Pulses delayed until
Pi is again listening

One pulse for Shutdown halt Two pulses for reboot

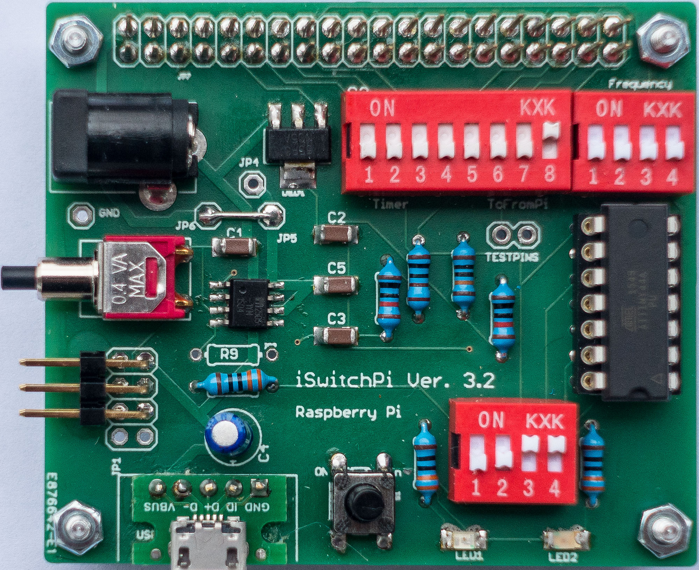
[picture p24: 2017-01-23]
Docu/pictures/iswitchpi-3.jpg

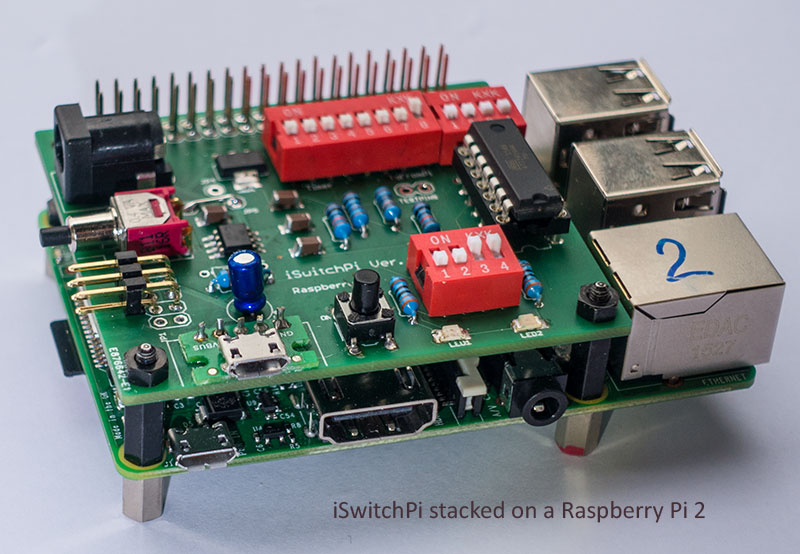
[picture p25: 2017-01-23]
Docu/pictures/iswitchpi-4.jpg

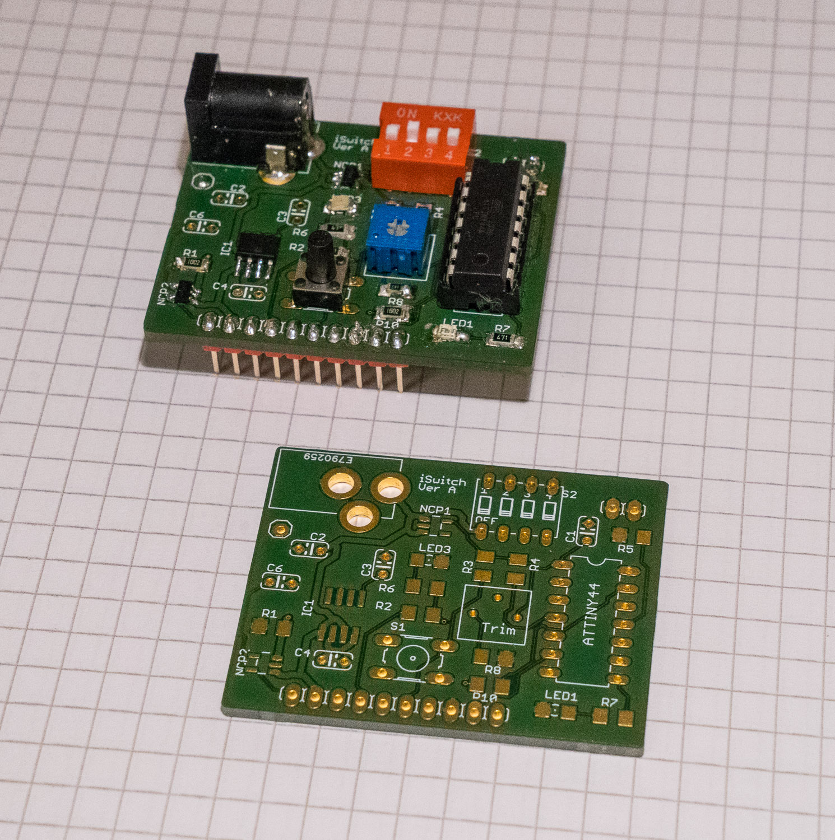
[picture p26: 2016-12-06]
Docu/supporting docu/iswitchpi_board-breadboard.jpg

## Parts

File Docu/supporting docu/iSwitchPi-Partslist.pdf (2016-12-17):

16.12.16 | iSwitchPi-Partslist.xlsx

# Parts List for iSwitchPi

Part | Value | Package | Note | Suppplier | PartNumber

Condensator
C1 | 1uF | C1206 | ceramic | Any
C2 | 1uF | C1206 | ceramic | Any
C3 | 1uF | C1206 | ceramic | Any
C4 | 100uF | E2,5-6E | | Any
C5 | 1uF | C1206 | ceramic | Any

IC
IC1 | MCU ATTINY44 | DIL14 | Attiny
IC2 | MIC2025-1YM | SO08 | High-Side Switch
LM117 | LM1171MP-3.3 | SOT223 | 3.3 Volt Regulator | Distrelec | 110-38-693

Led
LED1 | green | 1206 | SMD 1206
LED2 | orange | 1206 | SMD 1206

Resistor
R1 | 100k | 0204/7 | Any
R2 | 10k | 0204/7 | Any
R3 | 320 | 0204/7 | Any
R4 | 320 | 0204/7 | Any
R6 | 10k | 0204/7 | Any
R7 | 320 | 0204/7 | Any
R8 | 1k | 0204/7 | Any

DIP-Switch
S2 | DIP04S | Dip 4-Pol | Any
S3 | DIP08S | Dip 8-Pol | Any

16.12.16 | iSwitchPi-Partslist.xlsx

Pin Header
J1 | | 1X02 | Onboard green Led On/Off
J2 | | 1X02 | without Pi
JP1 | | 2X04 | Input/Output
JP2 | | 1X01 | TestPin
JP3 | | 1X01 | Optional 5 V IN
JP4 | | 1X01 | TestPin
JP5 | | 1X01 | 5 V to Pi, connect to JP6
JP6 | | 1X01 | 5 V to Pi, connect to JP5
JP7 | extra long pins | 2X20-BIG | GPIO Stacking Header | Adafruit | 2223

Pushbutton
S1 | 6x6 mm | B3F-10XX | Pushbutton On/Off | Adafruit | 367/1490/P0000025 6 P00000681

Other
IC-Socket 14-pol | for ATtiny44 | Any

5 Volt IN
PB3 | 2.1MMJACK | Barrel Jack 5.5/2.1 mm | Adafruit | 373
PB4 | ADAUSBMICRO | USB-Micro-Breakout | Adafruit, Play-Zone | 1833/P00001025

Optional, for variable Frequency Pulsgenerator
R5 | 320 | 0204/7 | | Any
RTRIM | 50k | | Trim Pot | Conrad | 447363

Optional, second Pushbutton On/Off
PB1 | Button liegend | Pushbutton On/Off | Distrelec | 135-75-923

### Montage

| Standoff | 4 Pieces | 11mm/2.5mm | Adafruit | 2336

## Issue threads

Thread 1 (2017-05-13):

Design-Rule-Check/Electrical-Rule-Check?

Deplora, 2017-05-13:
Hi,

thanks for your engagement in this project. I discovered it today and I find it really interesting. As a totally newbie to .brb files and Autodesk EAGLE I already have got a question/issue regarding this project...

I downloaded Autodesk _EAGLE 8.2.0 free_ for Ubuntu 16.04 LTS which seems to be the top recommended program for .brb-files in a lot of forums on the internet.

After I opened the iswitchpihat.brd with it I ran the Design-Rule-Check/Electrical-Rule-Check and then I was presented a lot of errors and warnings.

For example ...
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
"Stop Mask"

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
"Mehr als ein OUTPUT-Pin an Netz 3.3V"

Are these errors normal or should they be resolved in the design? Thanks in advance and this project will help me to learn how this stuff is done.

dakota127, 2017-05-14:
Hi

I get all the same errors in Eagle 7.7 and that did not prevent me from
havin the board properly manufactured.

Check out the net for eagle stop mask error - they seem to be kind of
normal. I simply did not caree about them.

https://electronics.stackexchange.com/questions/122722/stop-mask-errors-in-d
rc

So my advice: do not worry, the board is ok the way it is.

Greetings from Switzerland, Peter

----------------------------------------------------------------------------
-
Peter K. Boxler, Zürich, Switzerland
Bilder: Foto-Website <http://foto.descan.com>
Pi Hacks: Raspberry Hacks <http://projects.descan.com>
----------------------------------------------------------------------------
-
Life was much easier when Apple and Blackberry were simply fruits
----------------------------------------------------------------------------
- <http://projects.descan.com>

Hi,

thanks for your engagement in this project. I discovered it today and I find
it really interesting. As a totally newbie to .brb files and Autodesk EAGLE
I already have got a question/issue regarding this project...

I downloaded Autodesk EAGLE 8.2.0 free for Ubuntu 16.04 LTS which seems to
be the top recommended program for .brb-files in a lot of forums on the
internet.

After I opened the iswitchpihat.brd with it I ran the
Design-Rule-Check/Electrical-Rule-Check and then I was presented a lot of
errors and warnings.

For example ...
 <https://cloud.githubusercontent.com/assets/28679337/26030039/1c4b83ee-3846
-11e7-8564-7f60f5a57219.png>
"Stop Mask"

 <https://cloud.githubusercontent.com/assets/28679337/26030023/6608dbd6-3845
-11e7-9b7e-d2232debd7b4.png>
"Mehr als ein OUTPUT-Pin an Netz 3.3V"

Are these errors normal or should they be resolved in the design? Thanks in
advance and this project will help me to learn how this stuff is done.


You are receiving this because you are subscribed to this thread.
Reply to this email directly, view it on GitHub
<https://github.com/dakota127/iSwitchPi/issues/1> , or mute the thread
<https://github.com/notifications/unsubscribe-auth/AQpKlvdzXS01va3MrY-6YyQzx
FwAcfzMks5r5kDPgaJpZM4NaOd5> .

{"api_version":"1.0","publisher":{"api_key":"05dde50f1d1a384dd78767c55493e4b
b","name":"GitHub"},"entity":{"external_key":"github/dakota127/iSwitchPi","t
itle":"dakota127/iSwitchPi","subtitle":"GitHub
repository","main_image_url":"https://cloud.githubusercontent.com/assets/143
418/17495839/a5054eac-5d88-11e6-95fc-7290892c7bb5.png","avatar_image_url":"h
ttps://cloud.githubusercontent.com/assets/143418/15842166/7c72db34-2c0b-11e6
-9aed-b52498112777.png","action":{"name":"Open in
GitHub","url":"https://github.com/dakota127/iSwitchPi"}},"updates":{"snippet
s":[{"icon":"DESCRIPTION","message":"Design-Rule-Check/Electrical-Rule-Check
? (#1)"}],"action":{"name":"View
Issue","url":"https://github.com/dakota127/iSwitchPi/issues/1"}}}

Deplora, 2017-05-19:
Okay I understand.

Thank you Peter and wish you a happy weekend.

Closed 2017-05-19.

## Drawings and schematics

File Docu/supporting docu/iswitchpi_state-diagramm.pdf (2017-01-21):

1

### Stand By

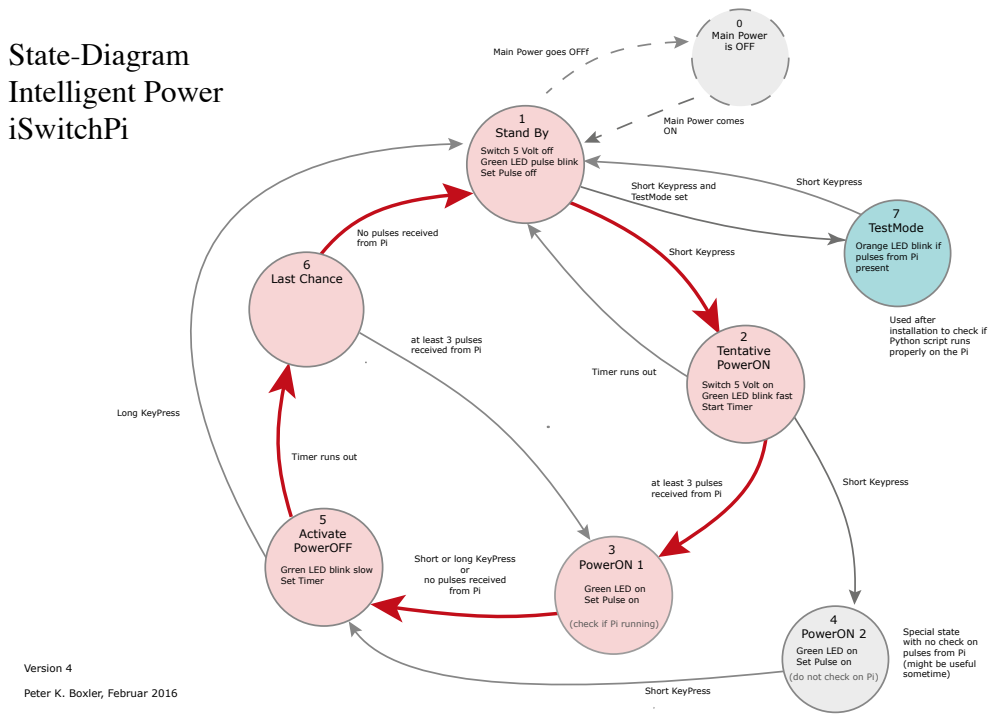
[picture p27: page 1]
Short Keypress; Short KeyPress; 5 Activate PowerOFF; Long KeyPress; 3 PowerON 1; 0 Main Power is OFF; 6 Last Chance; State-Diagram Intelligent Power iSwitchPi

Main Power goes OFFf

Main Power comes

Switch 5 Volt off
Green LED pulse blink
Set Pulse off

Short Keypress and
TestMode set

TestMode
Orange LED blink if
pulses from Pi
present

No pulses received
from Pi

Used after
installation to check if
Python script runs
properly on the Pi

at least 3 pulses
received from Pi

Tentative
PowerON
Switch 5 Volt on
Green LED blink fast
Start Timer

Timer runs out

Short or long KeyPress
no pulses received

Grren LED blink slow
Set Timer

Green LED on
Set Pulse on

PowerON 2
(do not check on Pi)

(check if Pi running)

Special state
with no check on
(might be useful
sometime)

Version 4
Peter K. Boxler, Februar 2016

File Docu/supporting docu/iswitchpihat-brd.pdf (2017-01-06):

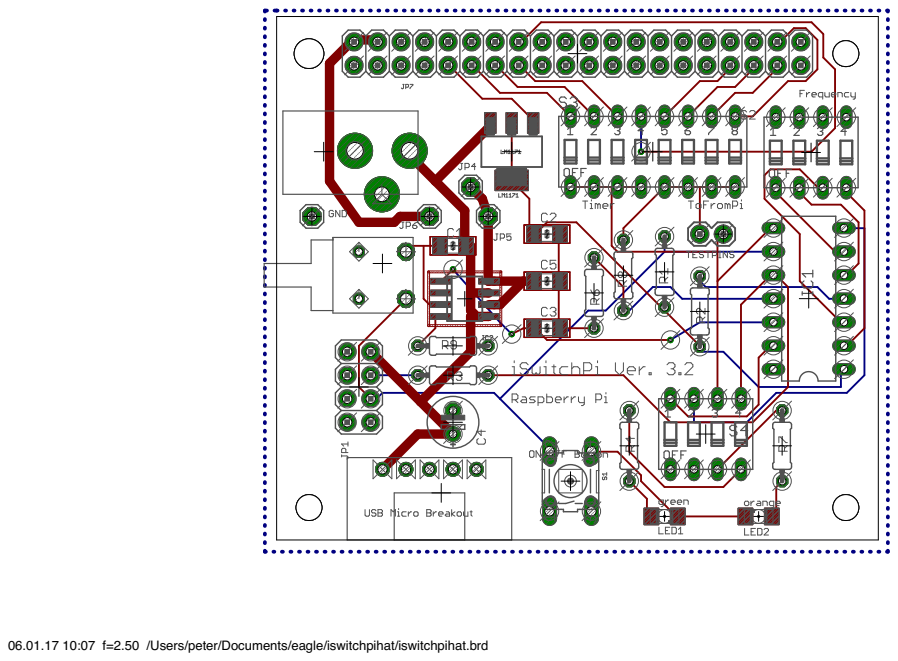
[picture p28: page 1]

06.01.17 10:07 f=2.50 /Users/peter/Documents/eagle/iswitchpihat/iswitchpihat.brd

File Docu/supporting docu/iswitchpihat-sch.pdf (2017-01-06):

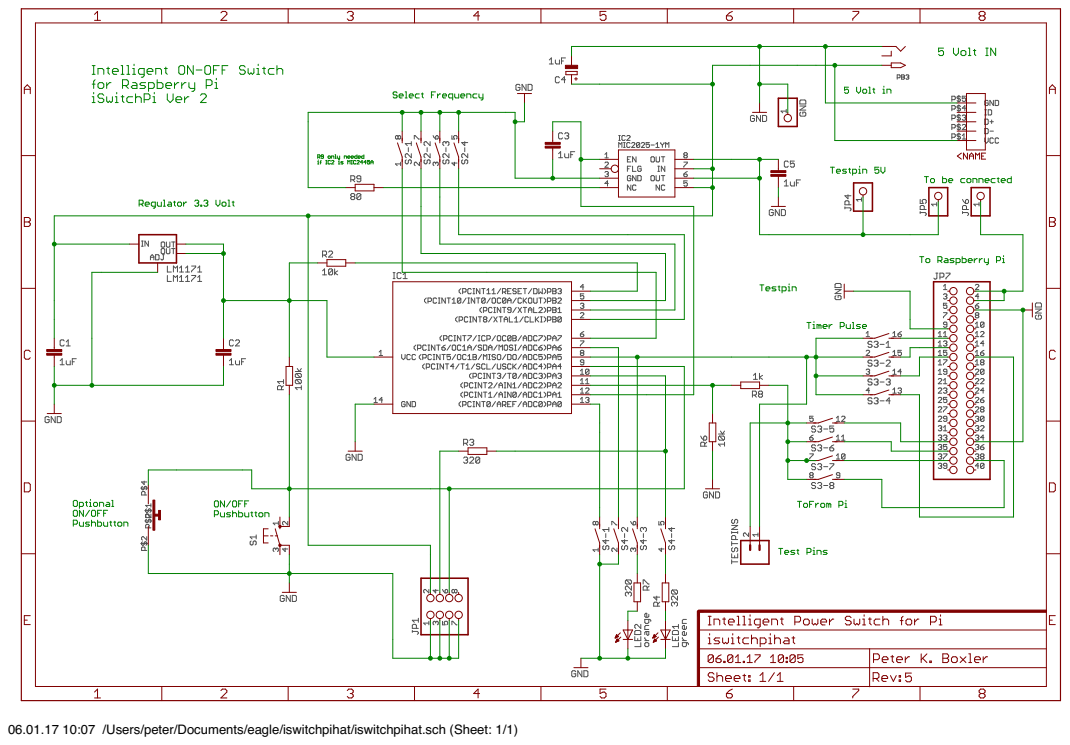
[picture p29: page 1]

06.01.17 10:07 /Users/peter/Documents/eagle/iswitchpihat/iswitchpihat.sch (Sheet: 1/1)

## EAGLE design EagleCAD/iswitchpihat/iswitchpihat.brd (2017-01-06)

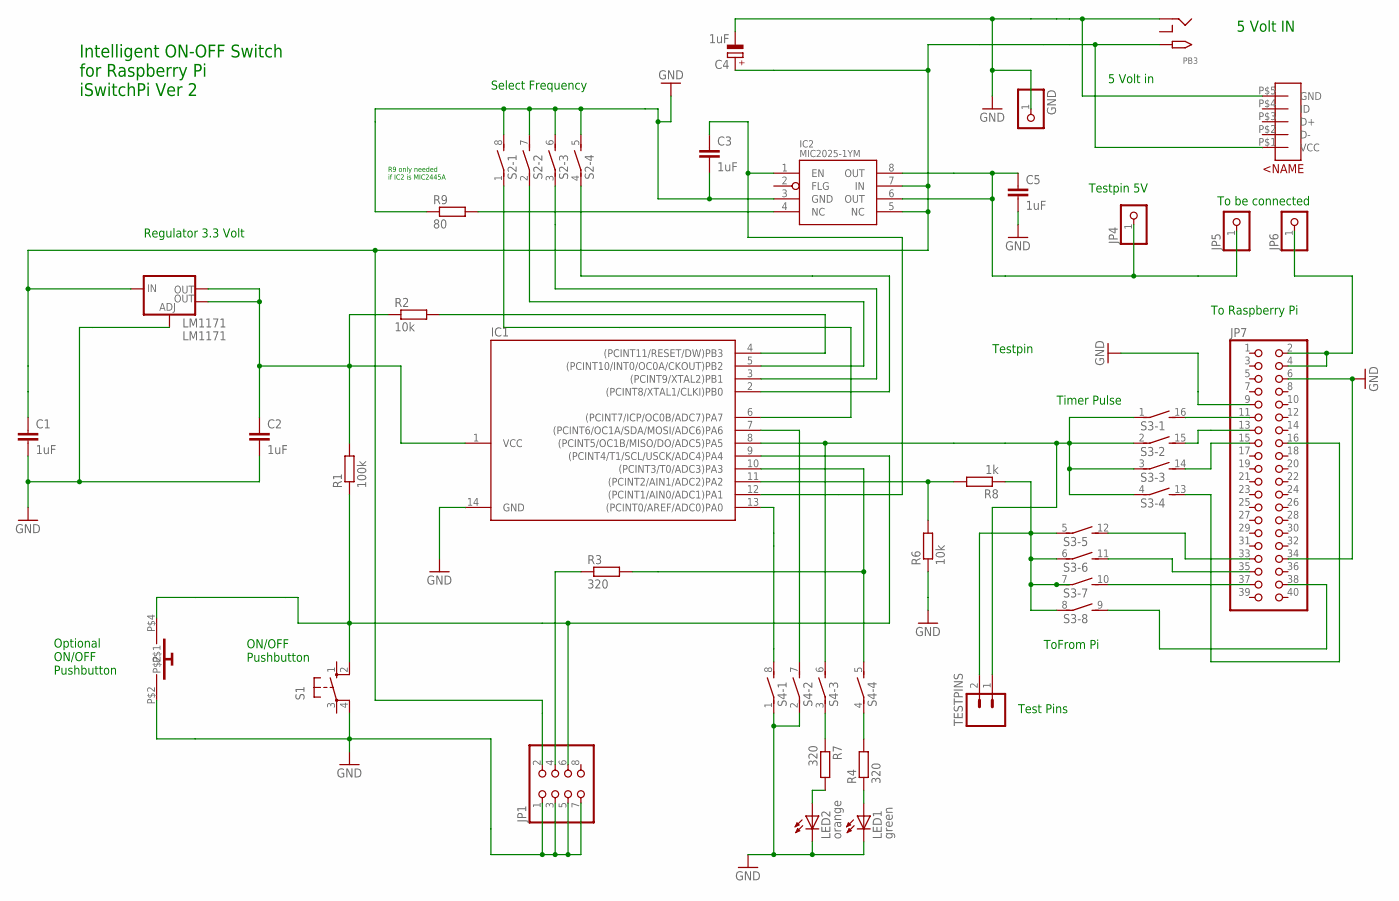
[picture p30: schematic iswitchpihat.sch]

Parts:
C1, C2, C3, C5: 1uF; C1206
C4: 1uF; E2,5-6E
GND: PINHD-1X1; 1X01
IC1: ATTINY24/44/84-PU; DIL14
IC2: MIC2025-1YM; SO08
JP1: PINHD-2X4; 2X04
JP4, JP5, JP6: PINHD-1X1; 1X01
JP7: PINHD-2X20-BIG; 2X20-BIG
LED1: green; 1206
LED2: orange; 1206
LM1171: LM1171; SOT223
PB1: PB6A-ELEDIS; PA52
PB3: 2.1MMJACK; ISWITCHPI_PJ-SMALLHOLES
PB4: USBMICRO; ADAUSBMICRO
R1: 100k; 0204/7
R2, R6: 10k; 0204/7
R3, R4, R7: 320; 0204/7
R8: 1k; 0204/7
R9: 80; 0204/7
S1: 10-XX; B3F-10XX
S2, S4: DIP04S
S3: DIP08S
TESTPINS: M02PTH; 1X02

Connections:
3.3V: C2.1, IC1.1 (VCC), LM1171.2 (OUT), LM1171.4 (OUT), R1.2, R2.1
5VIN: C1.1, C4.+, IC2.5 (NC), IC2.7 (IN), JP1.2, LM1171.3 (IN), PB3.TIP, PB4.P$1 (VCC)
5VOUT: C5.1, IC2.6 (OUT), IC2.8 (OUT), JP4.1, JP5.1
GND: C1.2, C2.2, C3.2, C4.-, C5.2, GND.1, IC1.14 (GND), IC2.3 (GND), JP1.1, JP1.3, JP1.5, JP1.7, JP7.6, JP7.9, JP7.34, LED1.C, LED2.C, LM1171.1 (ADJ), PB1.P$2, PB3.RING, PB4.P$5 (GND), R6.1, R9.1, S1.4 (P1), S2.5 (2), S2.6 (2), S2.7 (2), S2.8 (2), S4.1, S4.2 (1)
unnamed: IC1.9 ((PCINT4/T1/SCL/USCK/ADC4)PA4), JP1.6, PB1.P$4, R1.1, S1.2 (S1)
unnamed: IC1.6 ((PCINT7/ICP/OC0B/ADC7)PA7), S2.1
unnamed: JP7.11, S3.16 (2)
unnamed: IC1.4 ((PCINT11/RESET/DW)PB3), R2.2
unnamed: C3.1, IC1.12 ((PCINT1/AIN0/ADC1)PA1), IC2.1 (EN)
unnamed: IC1.11 ((PCINT2/AIN1/ADC2)PA2), R6.2, R8.2
unnamed: R8.1, S3.5 (1), S3.6 (1), S3.7 (1), S3.8 (1), TESTPINS.2
unnamed: IC1.10 ((PCINT3/T0/ADC3)PA3), R3.2, S4.5 (2)
unnamed: JP7.13, S3.15 (2)
unnamed: R7.1, S4.3 (1)
unnamed: LED1.A, R4.1
unnamed: JP1.4, R3.1
unnamed: LED2.A, R7.2
unnamed: JP7.15, S3.14 (2)
unnamed: JP7.16, S3.13 (2)
unnamed: R4.2, S4.4 (1)
unnamed: IC1.2 ((PCINT8/XTAL1/CLKI)PB0), S2.4 (1)
unnamed: JP7.38, S3.9 (2)
unnamed: IC1.5 ((PCINT10/INT0/OC0A/CKOUT)PB2), S2.2 (1)
unnamed: IC1.3 ((PCINT9/XTAL2)PB1), S2.3 (1)
unnamed: JP6.1, JP7.2, JP7.4
unnamed: JP7.37, S3.10 (2)
unnamed: JP7.35, S3.11 (2)
unnamed: JP7.33, S3.12 (2)
unnamed: IC1.7 ((PCINT6/OC1A/SDA/MOSI/ADC6)PA6), S4.7 (2)
unnamed: IC1.13 ((PCINT0/AREF/ADC0)PA0), S4.8 (2)
unnamed: IC1.8 ((PCINT5/OC1B/MISO/DO/ADC5)PA5), S3.1, S3.2 (1), S3.3 (1), S3.4 (1), S4.6 (2), TESTPINS.1
unnamed: IC2.4 (NC), R9.2

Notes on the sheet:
To Raspberry Pi
ON/OFF Pushbutton
Intelligent ON-OFF Switch for Raspberry Pi iSwitchPi Ver 2
5 Volt in
ToFrom Pi
Timer Pulse
Testpin
Testpin 5V
5 Volt IN
Optional ON/OFF Pushbutton
Regulator 3.3 Volt
Select Frequency
Test Pins
R9 only needed if IC2 is MIC2445A
To be connected

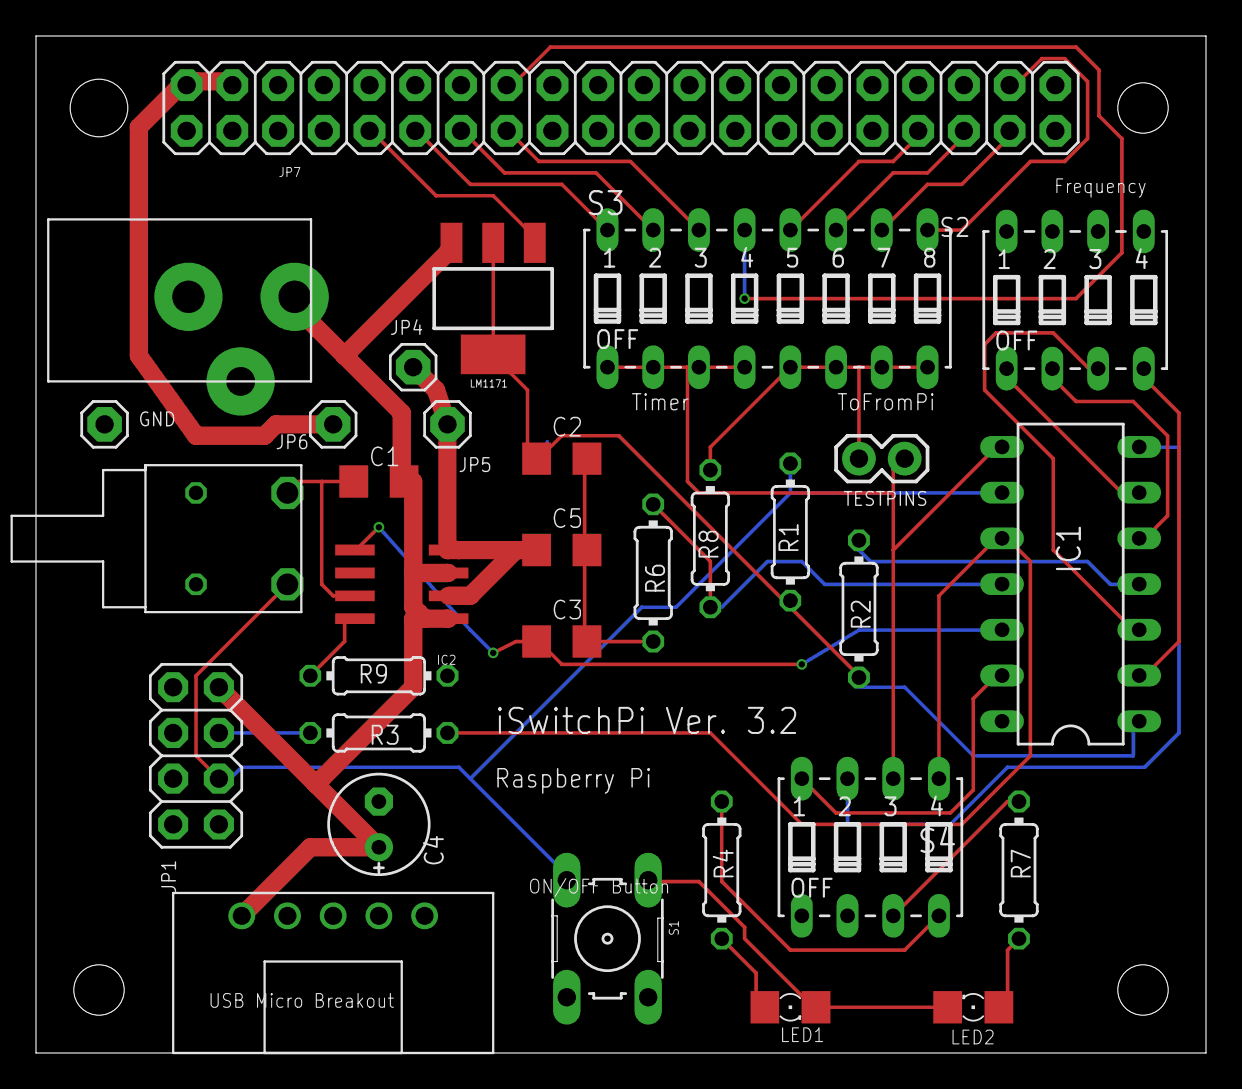
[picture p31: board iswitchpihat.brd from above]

Board: 2 copper layers, 65.0 x 56.5 mm, 32 parts (0 on the bottom side), 32 nets.

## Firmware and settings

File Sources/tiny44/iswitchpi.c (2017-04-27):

/************************************************************************/
/*                                                                      */
/*	Intelligent Power Switch for Raspberry Pi                           */
/*  																    */
/*	Implements Finite State Machine   with 7 States 	                */
/*	Pulsegeneration is done in square.c  [ functions pwm_xx() ]         */
/* 									                                    */
/*	See project description for full details				            */
/*                                                                      */
/*		ATTiny44  Pin Usage						                        */
/*	   				         ----o----                                  */
/*       	     	    VCC|       |GND									*/
/*     DIP 1   	    PB0|       |PA0		TESTPIN						    */
/*     DIP 2       	PB1|       |PA1		5V on/off						*/
/*     Reset       	PB3|       |PA2		TofromPi					    */
/*     DIP 3       	PB2|       |PA3		Led								*/
/*     TESTPIN      PA7|       |PA4		Pushbutton					    */
/*     Delay       	PA6|       |PA5		Squarewave out                  */
/*                	  	--------     					    		     */
/*                                                                      */
/*	Uses Timer0 for debouncing pushbutton and Timer1 for generation     */
/*  of square wave on Pin PA5  (Fast PWM mode)   						*/
/*											                            */
/* 	Includes Debouncing 8 Keys with Repeat Function by Peter Dannegger  */
/* 	Found here:  http://www.mikrocontroller.net/topic/48465             */
/*                                                                      */
/*                                                                      */
/* This c-Code runs on ATtiny44                                         */
/* Written by:                                                          */
/* Peter K. Boxler, December 2016                                        */
/************************************************************************/
//  Quelle und Diskussion des Debounce Code siehe hier:
//  http://www.mikrocontroller.net/topic/48465
//  Eintrag
//  Autor: Peter Dannegger (peda)
//  Datum: 16.06.2010 22:28
//------------------------------------------------------------------------

#include <avr/io.h>
#include <avr/interrupt.h>
#include <util/atomic.h>
#include <util/delay.h>
#include <square.h>                         // pwm functions for pulse generation

// define VERSION if board iswitchpi Version 1
//#define VERSION1
// #define F_CPU           1000000             // processor clock frequency - defined in Makefile !!
#define KEY_PORT        PINA                // Port A on ATtiny44
#define VPOWER          PINA1               // 5 Volt Power on/off
#define FROMPI          PINA2               // signal from and to Pi
#define LED1            PINA3               // green led
#define LED2            PINA5               // orange led (TESTMODE ONLY)
                                            // in normal mode used as Output Compare Pin OC1B see square.c
#define KEY0            PINA4               // pushbutton on Pin4
#if defined VERSION1                       // board version 2 has different Pin assignment
// version 1 TESTPIN
#define TESTPIN         PINA7               // TESTPIN to simulate pins from Pi
// version2
#else
#define TESTPIN         PINA0              // TESTPIN no pulses fromPi required
#define DELAYTIME       PINA6              // long or short wait times (selectable by Dip-switch 4 Pos 2 ON=short)
                                            // use short for Raspberry Pi 3 which boots/shutsdown faster
#define SQUARE          PINA7               // Pulsgeneration on/off (DIP Switch 1)
#define AUTO_POWER      PINB0               // Auto Power-on Input
#endif                                       // used in square.c
                                            // square wave output on  PINA5
// definitions for Debounce Code
#define REPEAT_MASK     (1<<KEY0)           // repeat: key0
#define REPEAT_START    100                 // after 1000ms
#define REPEAT_NEXT     20                  // every 200ms
// definitions for Debounce Code

#define POWEROFF_Delay_HALT_long     30           // seconds  (use 20 for test)
#define POWEROFF_Delay_HALT_short    15           // seconds  (use 20 for test)

#define POWEROFF_Delay_REBOOT_long   50           // seconds  (use 20 for test)
#define POWEROFF_Delay_REBOOT_short  20           // seconds  (use 20 for test)

#define PULSCHECK               4           // 10 times 10 ms intervall check pulses from Pi
#define PULSCHECK_SECONDS       6           // ccount pulses from Pi during this time

#define POWERON_Delay_long      50          // seconds (use 20 for test)
#define POWERON_Delay_short     20          // seconds (use 20 for test)

#define POWERON_Blink_int  15               // 15 x 10 ms
#define POWEROFF_Blink_int 60               // 60 x 10 ms
#define TESTMODE_Blink_int 300              // 200 ms
#define REGULAR_Blink       1
#define PULSED_Blink        2
#define STANDBY_Blink_int_on   3
#define STANDBY_Blink_int_off  250          // can be max 255

#define PULSELENGTH1  80                    // Signal to PI , ms
#define PULSELENGTH2  500                    // Signal to PI , ms

#define STAT0_FIRST     0                      // bit Position für First Time Switch
#define STAT1_FIRST     1                      // bit Position für First Time Switch
#define STAT2_FIRST     2                      // bit Position für First Time Switch
#define STAT3_FIRST     3                      // bit Position für First Time Switch
#define STAT4_FIRST     4                      // bit Position für First Time Switch
#define STAT5_FIRST     5                      // bit Position für First Time Switch
#define STAT6_FIRST     6                      // bit Position für First Time Switch
#define STAT7_FIRST     7                      // bit Position für First Time Switch

static unsigned char sekunde;
static unsigned char sekunde2;

static unsigned char tick;				// tick Timer 0
static unsigned char tick2;				// tick Timer 0
static unsigned char tick3;				// tick Timer 0
uint8_t blinkint;                           // blink intervall
uint8_t blinkwhat;                          // blink intervall
uint8_t blinkon;                            // blink ON=1  (Standby blink only
uint8_t poweroff_delay;                     // either POWEROFF_Delay_HALT_long or POWEROFF_Delay_REBOOT_long
uint8_t key_state;                          // debounced and inverted key state:
uint8_t poweron_delay;                     //

                                            // bit = 1: key pressed
uint8_t key_press;                          // key press detect
uint8_t key_rpt;                            // key long press and repeat
volatile uint8_t key_release;               // key release detect

enum {
    state0,                                      // finite state machins states
    state1,
    state2,
    state3,
    state4,
    state5,
    state6,
    state7
    };
static uint8_t first_time = 0xff;                // first_time run through a state, bitwise, bit 0 means state 1
static uint8_t state=state0;                       // state variable
static uint8_t pipulses=0;                          // key press detect
static uint8_t waslo=1;                  // key press detect
static uint8_t washi=0;                  // key press detect
volatile static uint8_t sendnow=0;
static uint8_t pastpulses=0;
void mytimer(void);
void sendtopi(int);
void sendtopi_2(int);

//-------------------------------------------------------------------
// debounce functions from Peter Dannegger
// http://www.mikrocontroller.net/topic/tasten-entprellen-bulletproof
// http://www.mikrocontroller.net/topic/48465
//-------------------------------------------------------------------
uint8_t key_clear( uint8_t key_mask )
{
  ATOMIC_BLOCK(ATOMIC_FORCEON){
    key_press &= ~key_mask;                      // clear key(s)
  }
  return (0x0);
}

uint8_t get_key_press( uint8_t key_mask )
{
  ATOMIC_BLOCK(ATOMIC_FORCEON){
    key_mask &= key_press;                      // read key(s)
    key_press ^= key_mask;                      // clear key(s)
  }
  return key_mask;
}

uint8_t get_key_rpt( uint8_t key_mask )
{
  ATOMIC_BLOCK(ATOMIC_FORCEON){
    key_mask &= key_rpt;                        // read key(s)
    key_rpt ^= key_mask;                        // clear key(s)
  }
  return key_mask;
}

uint8_t get_key_release( uint8_t key_mask )
{
  cli();                     // read and clear atomic !
  key_mask &= key_release;   // read key(s)
  key_release ^= key_mask;   // clear key(s)
  sei();
  return key_mask;
}

uint8_t get_key_short( uint8_t key_mask )
{
  uint8_t i;

  ATOMIC_BLOCK(ATOMIC_FORCEON)
    i = get_key_press( ~key_state & key_mask );
  return i;
}

uint8_t get_key_long( uint8_t key_mask )
{
  return get_key_press( get_key_rpt( key_mask ));
}

uint8_t get_key_long_r( uint8_t key_mask )      // if repeat function needed
{
  return get_key_press( get_key_rpt( key_press & key_mask ));
}

uint8_t get_key_rpt_l( uint8_t key_mask )       // if long function needed
{
  return get_key_rpt( ~key_press & key_mask );
}
// --- Ende debounce functions   ----------------------


//----------------------------------------------------
// --- Interrupt Service Routine for Timer/Counter 0
//  this code runs every 10 ms activated by Timer 0 compare_match
// this is Parer Danneggers Code
//----------------------------------------------------
ISR( TIM0_COMPA_vect )                          // every 10ms
{
  static uint8_t ct0 = 0xFF, ct1 = 0xFF, rpt;
  uint8_t i;

  i = key_state ^ ~KEY_PORT;                     // has key-input changed ?
  ct0 = ~( ct0 & i );                           // reset or count ct0
  ct1 = ct0 ^ (ct1 & i);                        // reset or count ct1
  i &= ct0 & ct1;                               // count until roll over ?
  key_state ^= i;                               // then toggle debounced state
  key_press |= key_state & i;                   // 0->1: key press detect
  key_release |= ~key_state & i;                // 1->0: key release detect

  if( (key_state & REPEAT_MASK) == 0 )          // check repeat function
     rpt = REPEAT_START;                        // start delay
  if( --rpt == 0 ){
    rpt = REPEAT_NEXT;                          // repeat delay
    key_rpt |= key_state & REPEAT_MASK;
  }

    mytimer();              // handle my own timer stuff

}

//----------------------------------------------------
// --- Interrupt SubRoutine - called by regular ISR
//  this code runs every 10 ms activated by Timer 0 compare_match
//----------------------------------------------------
void mytimer()   {                       // every 10m{
// count ticks (one tick every 10 ms)
    tick++;                             // tick is used for adding seconds
    tick2++;                            // tick2 is used for led blinking
    tick3++;                            // tick3 is used for Pi related stuff

    if(tick > 100) {                     // 100 times 10 ms equals a second
        sekunde++;                       // seconds used for poweron/off delays
        sekunde2++;                      // seconds used for pulses from pi
        tick = 0;
    }


// now do Pi related stuff ---------------------

    if (tick3 > PULSCHECK)  {            // every PULSCHECK times 10 ms: check pulses from Pi
        tick3=0;                         // and send signal to Pi if key was pressed (and only then)
                                          // check signal from Pi every 100 ms
                                          // Pin FROMPI ist set to Input
        if (PINA & (1<<FROMPI))       // pin ist high
            {
            if (waslo==1)  {             // Pi signals I am alive, pin was low before, goes to high
                washi=1;
                pipulses++;              // count pulses from Pi
                waslo=0;
                }
            }
        else if (washi==1) {            // Input is low again
            waslo=1;                    // if we have to send something, do it now!!
            washi=0;

            if (sendnow != 0)  {           // we need to send puls(es) to the Pi
                _delay_ms(100);             // give the Pi time to set up its IR Handler
                sendtopi(sendnow);         // variable sendnow says how many (one or two)
                sendnow=0;                 // no more to be sent
                }
            }
    }       // end check Pi

    // store number of pulses that came in within the last PULSCHECK_SECONDS seconds and reset counter
    if (sekunde2 > PULSCHECK_SECONDS) {           // for PULSCHECK_SECONDS seconds we count pulses from pi
        pastpulses=pipulses;            // store number of pulses
        pipulses=0;                     // reset puls counter
        sekunde2=0;
        }

// done with th Pi related stuff

}

//----------------------------------------------------
// --- Function blink orange led  (TESTMODE ONLY)
//----------------------------------------------------
void blink_led() {
    PORTA |= (1<<LED2);               //orange led on
    _delay_ms (TESTMODE_Blink_int);
    PORTA &= ~( 1<<LED2);             //one pulse
    _delay_ms (50);

    }

//----------------------------------------------------
// --- Fuction send pulses to pi
//  send simple pulses
//----------------------------------------------------
void sendtopi(int what) {

    DDRA  |= (1<<FROMPI)  ;                 // Switch line to Pi to output
    PORTA |= (1<<FROMPI);                   //signal to pi halt
     _delay_ms(PULSELENGTH1);
    PORTA &= ~( 1<<FROMPI);                 //one pulse

    if (what==2) {
        _delay_ms(PULSELENGTH2);            //pause
        PORTA |= (1<<FROMPI);               //signal to pi halt
        _delay_ms(PULSELENGTH1);
        PORTA &= ~( 1<<FROMPI);             //one pulse
        }
    DDRA  &= ~(1<<FROMPI);                  // set to Input again (from Pi)

 }


//-------------------------------------------------------
// ---- MAIN Program
//-------------------------------------------------------
int main( void )
{
// Set all Ports
    DDRA   =  1<<LED1 | 1<<VPOWER ;                 // output signals
    DDRA  &= ~(1<<FROMPI);                          // set to Input (from Pi)
    DDRA  &= ~(1<<TESTPIN);                        // set to Input (TESTPIN) is used for simulation without pulses from Pi
                                                    // used for Testing ONLY, must be not connected
                                                    // for normal operation !!
	DDRB &= ~(1<<AUTO_POWER);                            // input DIP 2 Position 4   auto-power-on
                                                    
    PORTA |= (1<<TESTPIN);                         //  set pullup
    DDRA  &= ~(1<<DELAYTIME);                       // Select Timer values for on/off  (use short for Pi 3)
    PORTA |= (1<<DELAYTIME);                        //  set pullup
    PORTB |= (1<<AUTO_POWER);                            // pull up auto-power-on
 
    PORTA &= ~(1<<FROMPI);                         // no pullup - has external pulldown
    PORTA &= ~( 1<<LED1 | 1<<VPOWER );             // all outputs off

    PORTA &= ~(1<<KEY0);                           // no pullup on Key-Input, has external pullup

    // TIMER 0 konfig - used for Peter Dannegger's debounce-Functions
    TCCR0A = 1<<WGM01;                             // Timer0 Mode CTC
    TCCR0B = 1<<CS02 | 1<<CS00;                    // Timer/Counter0 source is F_CPU / 1024
    OCR0A = F_CPU / 1024.0 * 10e-3 - 0.5;          // 10 ms compare Value for counter/timer (Prescaler: 10ms interrupt)
    TIMSK0 = 1<<OCIE0A;                             // Enable compare Match interrupt on Timer/Counter 0
                                                    // Achtung: TIMSK für tiny85 und TIMSK0 für tiny44

    pwm_init();                                     // setup Timer 1 for variable pulse on PA5 also set PORTB
    sei();                                          // Interrupt enable
    blinkwhat=0x00;                                 // do not blink
    first_time = 0xff;                                   //bits for first_time run thru the states
                                                    // bit 0: state 0
                                                    // bit 1: state 1
                                                    // bit 2: state 2
                                                    // etc.
    state=state0;                       // state variable
    PORTA &= ~( 1<<LED1 | 1<<VPOWER);   // all outputs off

    if ( !(PINB & (1<<AUTO_POWER)) )   // check if auto power on is required (dip switch Pos 4 ON)
            state=state2;           // if YES: next state is state 2   
        else
            state=state1;           // if NO: next state is state 1  

   _delay_ms(10);                       // for testing

//
// ---- Main Loop. forever ---------------------
// ---- Implements State Machine ---------------
  for(;;)
  {
 //   _delay_ms(10);                                // for testing

    switch (state) {
/*------------------------------------------------------------------*/
/*  state 0  Initial State State                                    */
/*  is entered upon 5 Volt Power on                                 */
/*  check if Pi auto power-on is selected  (dip Switch)             */
/*  if NO --> goto state 1                                          */
/*  if YES --> goto state 2                                         */
/*------------------------------------------------------------------*/
    case state0:
        if (first_time & (1<<STAT0_FIRST)) {    // first_time time throu ?
            first_time =0xff;                   // set first_time all other states
            first_time &= ~(1<<STAT0_FIRST);              // clear first_time this state
        }
        tick2=0;
        pastpulses=0;                       // pulse counter reset (pulses from Pi)
 
        if ( !(PINB & (1<<AUTO_POWER)) )   // check if auto power on is required (dip switch Pos 4 ON)
            state=state2;           // if YES: next state is state 2   
        else
            state=state1;           // if NO: next state is state 1  

    break;
 
/*------------------------------------------------------------------*/
/*  state 1  Stand-by State, all is off, waiting for short keypress  */
/*  Power to Pi ist off, led blinks short pulses                                 */
/*  Waiting for short keypress                                      */
/*------------------------------------------------------------------*/
    case state1:

        if (first_time & (1<<STAT1_FIRST)) {    // first_time time throu ?
            PORTA &= ~( 1<<LED1 | 1<<VPOWER);   // all outputs off
            key_clear( 1<<KEY0 );
            blinkwhat=PULSED_Blink;
            tick2=0;
            blinkon=1;
            pwm_stop();							// stop pulse genaration output on PA5
            pastpulses=0;                       // pulse counter reset (pulses from Pi)
            first_time =0xff;                   // set first_time all other states
            first_time &= ~(1<<STAT1_FIRST);    // clear first_time this state
            }
        if  (get_key_short( 1<<KEY0 )) {         // get debounced keypress
            if (!(PINA & (1<<TESTPIN)) )         // if Testpin is low: signalling TESTMODE
                state=state7;                       // next state is state 7
            else
                state=state2;                       // next state is state 2
            }                                   // leaving standby
    break;

/*------------------------------------------------------------------*/
/*  state 2  Tentative Power on, waiting for Pi to come up          */
/*  Power to Pi ist on, led is blinking fast                        */
/*  Short keypress switches to state 4   (power on without checking */
/*  whether Pi is on)                                               */
/*------------------------------------------------------------------*/
    case state2:

        if (first_time & (1<<STAT2_FIRST)) {     // first_time time throu ?
            PORTA |= (1<<VPOWER);               //switch 5 volt power on
            poweron_delay=POWERON_Delay_long;
            if ( !(PINA & (1<<DELAYTIME)) ) {
              poweron_delay=POWERON_Delay_short;            // check pin PA6 for delay times (Dip-switch 4 Pos 2 ON)
            }

            blinkwhat=REGULAR_Blink;
            blinkint=POWERON_Blink_int;
            tick2=0;                            //start timer
            sekunde=0;
            pwm_start();						            // start pulse generation output on PA5
            first_time =0xff;                   // set first_time all other states
            first_time &= ~( 1<<STAT2_FIRST);    // clear first_time this state
            }

        pwm_check();

        if ((blinkwhat>0) && (sekunde > poweron_delay))  {
            blinkwhat=0;
            state=state1;                       // Pi did not come on, so gaback to stand by
            }

        if  (get_key_short( 1<<KEY0 ))  {        // get debounced keypress short
            blinkwhat=0;
            state=state4;
           }
                    // how many pi pulses have we received ? if we have Pi is alive
                    // so we go to state 3 (normal operation state)
        if (pastpulses > 3) {state=state3;}

    break;
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

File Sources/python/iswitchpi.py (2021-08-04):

#!/usr/bin/python
# coding: utf-8
#--------------------------------------------------------------------------
#   Pi  Shutdown Script
#   Version 3
#   Works together with the Intelligent Power Switch ISWITCHPI
#   Only one GPIO pin is used to communicate with the ISWITCHPI
#
#   Communication GPIO Pin selectable with commandline option -p
#   Default Pin is GPIO 20
#   Valid Pin Number 13,19,20 and 26  (as defined on the iSwitchPI PCB)
#
#   Testing: run script with commandline option -d 0 , -d 1 or -d 2
#             (note: use -d 0 if quit is neeed (no output)
#   WARNING: Do not change time/sleep values, they correspond to what iswitchpi does
#
#   Note:   killfiles are use for testing only: we can check if Signals from OS are treated ok
#           by looking for killfiles in the sripts directory
#
#   by Peter Boxler, Februar 2016
#
# Modifications:
# Dec. 2016 optparse replaced by argparse
# August 2021  print mit () versehen....

# ------------------------------------------------------------------------
#
# Import the modules to send commands to the system and access GPIO pins
from subprocess import call
import RPi.GPIO as GPIO

from time import sleep
import time, datetime
import argparse
import sys, os, re
import signal
#
#
ret=0;
debug=0                 # set this to 1 or 2 mit Commandline ar -d
appname=""              # script name
pfad=""                 # path where script runs
start_time=0            # time start
intervall=0             # time intervall for signalling pulses from ISWITCHPI
INTERVALLMAX=1          # max waittime for second pulse
PULSE=0.05              # Pulse lenght in sec for I am alive pulses to ISWITCHPI    
anzir=0                 # Interrupt Counter
sleeptime=0.1           # DO NOT CHANGE THIS - DEPENDENT ON PULSES SENT BY ISWITCHPI.C (ATtiny44)
sleepbeforedown=2
kill_shellscript="/home/pi/myservices/killjobs.sh"
killfile="iswitch-kill"

# killcomm="kill $(ps aux | grep tr_main | awk '/python/ {print $2}')"

# ------ Function Definitions -----------------------------
#----------------------------------------------------------
# get and parse commandline args
def argu():
    parser = argparse.ArgumentParser()

    parser.add_argument("-d", help="debug", default=1,
                    type=int)
    parser.add_argument("-p", help="gpio", default=20,
                    type=int)

    args = parser.parse_args()
#   print (args.d, args.p)          # initial debug
    return(args)
    
#----------------------------------------------
#-- Class for Graceful termination
class GracefulKiller:
  kill_now = False
  def __init__(self):
    signal.signal(signal.SIGINT, self.exit_gracefully)
    signal.signal(signal.SIGTERM, self.exit_gracefully)

  def exit_gracefully(self,signum, frame):
      if debug==2: print ("iSwitchPi: Signal received:{} ".format( signum)) 
      tmp = killfile + "-" + '{:2d}'.format(signum) + ".txt"
      killit=open(tmp,"w")  # write killfile, so we know this was done
      killit.close()
      if debug==2: print ("iSwitchPi: Return in Signalhandler.. ")
      self.kill_now = True
      
#------------------------------------------------
# delete ev. vorhandene killfiles
def purgekf(dir, pattern):
    for f in os.listdir(dir):
        if re.search(pattern, f):
    	 #   if debug == 2: 
         #       print ("iSwitchPi: killfile {} removed".format(f) )
            os.remove (os.path.join(dir,f))


# -----------------------------------------------------------------
# check selected GPIO Pin
def gpio_pincheck(pin):
    
    if ((pin == 13) or (pin == 19) or (pin==20) or (pin==26)) :
      if debug==1:   print ("iSwitchPi: Selected ComPin: %d\n" % pin)
      return();
    print ("iSwitchPi: Selected GPIO %d not valid (use 13,19,20 or 26)" % pin)
    print ("iSwitchPi: Terminating")

    return(99);   

# -----------------------------------------------------------------
# Define a function to run when an interrupt is called
def my_callback(channel):
    global state,sleeptime,anzir;
    
#    sleeptime=0         # starting now we do not sleep in main loop
    if debug==2:   print ("iSwitchPi: Shutdown GPIO-Pin Rising: %d" % channel)
    anzir=anzir+1
#    GPIO.remove_event_detect(channel);
#    state=2;
    return();   

#----------------------------------------------------
# what do we need to do: halt or reboot the Pi
def shutdown(what):
    GPIO.remove_event_detect(com_gpio_pin);
    GPIO.setup(com_gpio_pin, GPIO.OUT)       # Set GPIO Pin to output again


    if (what==1):                # high means halt, low means reboot
    
        if debug==1: print ("\niSwitchPi: detected HALT")
        if debug==2:           # debug mode do nothing exept print
            print ("iSwitchPi: Shutdown reached... Halting")
            GPIO.output(com_gpio_pin,False)
            GPIO.cleanup(com_gpio_pin)
            sys.exit(0)
        else:
            try:
                call (kill_shellscript)
            except:
                pass;
            sleep(0.2)
            GPIO.output(com_gpio_pin,False)
            GPIO.cleanup(com_gpio_pin)
            sleep(sleepbeforedown)
            call('halt', shell=False)   # halt the Linux System
            return(0)
    else:
        if debug==1: print ("\niSwitchPi: detected REBOOT")

        if debug==2:           # debug mode do nothing exept print
            print ("iSwitchPi: Shutdown reached... Rebooting")
            GPIO.output(com_gpio_pin,False)
            GPIO.cleanup(com_gpio_pin)
            sys.exit(0)
        else:
            try:
                call (kill_shellscript);
            except:
                pass;
            sleep(0.2)
            GPIO.output(com_gpio_pin,False)
            GPIO.cleanup(com_gpio_pin)
            sleep(sleepbeforedown)
            call('reboot', shell=False)   # reboot the Linux System
            return(0)
        

# Function initialize() ----------------------------------------
def initialize():
    global start_time, appname;
    GPIO.setmode(GPIO.BCM)
    GPIO.setwarnings(False)
    sleep(0.2)
    GPIO.setup(com_gpio_pin, GPIO.IN)       # Set GPIO Pin to input
    GPIO.add_event_detect(com_gpio_pin, GPIO.RISING, callback=my_callback)

    if debug==2: print ("iSwitchPi: initialize done");
    return();

# Function send pulses to ISWITCHPI
#-------------------------------------------------------
def sendpulse():  # blink led 
    GPIO.output(com_gpio_pin, True)
    sleep(PULSE)
    GPIO.output(com_gpio_pin, False)
    sleep(PULSE)
    if debug==2: print ("iSwitchPi: pulses sent...");
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

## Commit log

2016-12-11 board updated, partslist added
2016-12-16 debug prints enhanced
2016-12-18 eagle files added
    [iswitchpihat.brd, iswitchpihat.sch]
2016-12-18 optparse replaced with argparse
    [iswitchpi.py]
2017-01-02 pcb board updated:dip switch moved
2017-01-04 small changes
    [iswitchpihat.brd]
2017-01-06 many thing updated for new board
    [iswitchpihat.brd, iswitchpihat.sch]
2017-01-08 new board documented
2017-01-21 docu updated - new board
2017-04-27 Auto-power-on added
2021-08-04 print statements modified for python3

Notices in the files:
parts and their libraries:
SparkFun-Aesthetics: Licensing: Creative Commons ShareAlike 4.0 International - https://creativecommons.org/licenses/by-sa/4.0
